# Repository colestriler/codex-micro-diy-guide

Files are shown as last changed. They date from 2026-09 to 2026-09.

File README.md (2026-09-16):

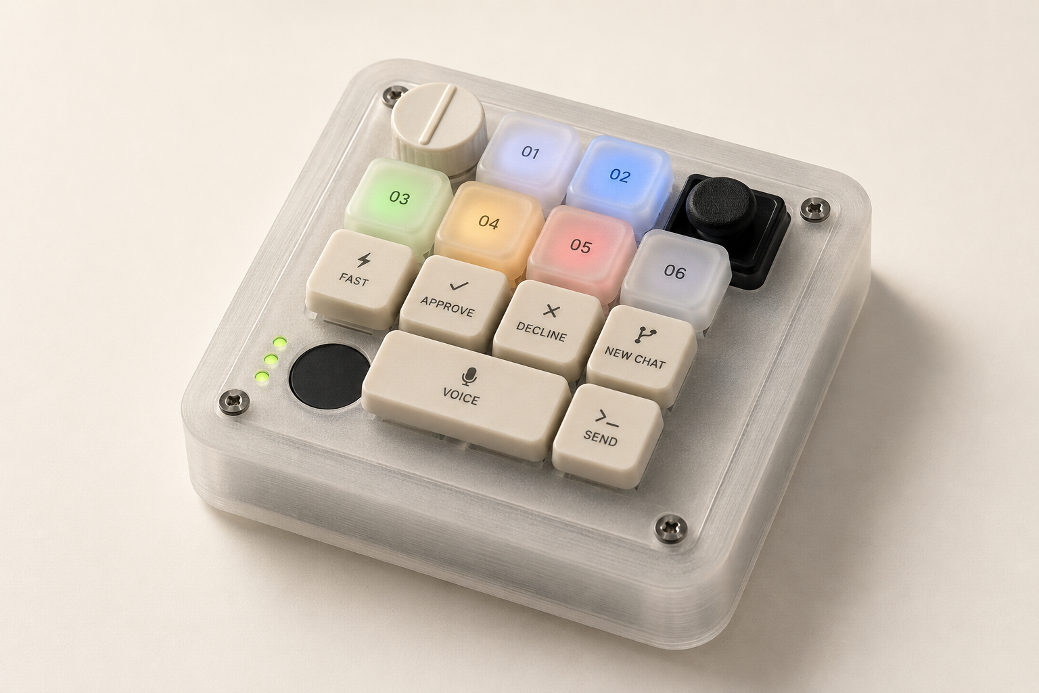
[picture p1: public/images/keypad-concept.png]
Concept render of the DIY Codex Micro keypad with numbered agent keys and labeled controls (https://codexmicro.diy)


*AI-generated concept render of the DIY prototype, with functional key labels.*

# I wanted the OpenAI keyboard, but it was sold out.

So I decided to build one. 

I wanted to buy the [OpenAI × Work Louder Codex Micro](https://openai.com/supply/co-lab/work-louder/). Small keyboard, little dial, glowing keys. Very much my kind of thing.

I have a 3D printer. So I decided to put together a guide to making my own version—and share the files for anyone who wants to do the same.

This is that guide: a way to explore the parts, watch how they fit together, download the CAD, and work through the build. Credit for the original device goes to OpenAI and Work Louder. This project is a tutorial for a DIY recreation of their Codex Micro.

**[Open the interactive build guide →](https://codexmicro.diy)**

## What's here

- An interactive 3D model. Click a part for its print files or a purchase link for bought components.
- An eleven-stage assembly animation, including the bits hidden inside the case.
- Ten clickable assembly lessons with focused CAD views, before/after and replay controls, wiring diagrams, and explanations of how and why each step works.
- Printable STL files, editable STEP files, and parametric CAD source.
- A compact parts checklist that saves your selections in your browser, plus filament choices, wiring, assembly instructions, and starter firmware.
- One continuous page with a table of contents in build order.

## Where the build stands

The CAD is a dimensioned prototype reconstructed from the reference layout and standard parts. It is not the manufacturer's CAD. Earlier enclosure revisions have been printed, and the knob button and rotation have been bench-tested. The latest joystick/tray fits, LED illumination and complete keyboard still need physical confirmation.

The custom KB2040 firmware provides generic USB inputs and manual LED control. **It does not yet reproduce the full native Codex integration.** OpenAI documents native support for the genuine Codex Micro and Creator Micro 2. Retaining genuine electronics is the documented route to those features; adapting the printed case to a donor board still requires measurements and a mechanical revision.

The guide explains both routes so you can decide what to build before buying a pile of parts.

The printable keycaps were updated on September 13, 2026 with flat tops, rounded corners and a 0.5 mm beveled rim for easier printing and labeling. This applies to the shared white/clear single cap and the wide white cap. Start with a stem-fit coupon and one cap before printing the set. The main assembly viewer includes the flat keycaps but retains the older mount and individual baffles. Use the current revision guides for the latest joystick and tray; the hero remains a concept illustration.

## Current CAD downloads

Download the [current STEP set](https://codexmicro.diy/downloads/current-cad/Codex-Micro-current-STEP.zip): 14 current parts and fit samples, plus a partial mounting reference assembly. **Mounting v5** puts the tray screws underneath and the heat-set inserts in bosses under the upper plate. The joystick sits on a separate adapter with locating pegs and raised tab supports. The 10 × 4 mm LED openings and flat keycaps are retained.

Start with the four small prints: upper/lower tray-joint samples, joystick corner and adapter. Reuse the tested adapter in the finished keyboard. Both full plates are new matched v5 parts and remain **WAIT** until both fit tests pass. Reuse M3 × 8 tray screws and M3 × 4 inserts; the joystick needs two longer **M1.6 × 10 mm screws** with the existing nuts. [Interactive CAD and print guide](https://codexmicro.diy/downloads/mounting-v5/guide.html).

Retired mounts, shims and individual baffles are excluded from the current STEP set; historical kits remain in the complete archive.

Run `python3 scripts/package-current-cad.py` after updating a revision kit to synchronize the current exports, refresh the STEP bundle and rebuild the complete archive. The manifest records the source and hash of every included STEP file.

## Run the site

Requires Node.js 22 or newer.

```sh
npm ci
npm run viewer
npm run dev
```

Open `http://localhost:3007`.

```sh
npm run build
npm start
```

`npm run build` regenerates the viewer and checks the catalog, model mappings, geometry buffers, and download links before building Next.js.

The live site is hosted on Vercel. Pushing to `main` automatically builds and deploys the site.

## Project map

- `app/` and `components/`: the single-page Next.js app.
- `data/parts.json`: part descriptions, quantities, specifications, purchase links, and print files.
- `data/instructions.json`: the checked-in assembly, printing, compatibility, and software instructions.
- `data/assembly-lessons.json`: the ten lessons, their part lists and resources, and which CAD components each focused view shows.
- `viewer-src/`: the Three.js assembly player, actual CAD meshes, and model-to-catalog mappings.
- `public/downloads/`: the complete CAD, wiring, firmware, original offline guide, and build package.

To update the model, edit `viewer-src/assembly.js` or its source geometry, then run `npm run viewer`. Every selectable model component maps to a catalog entry in `viewer-src/part-map.json`; subcomponents such as LED boards and copper foil have their own part identifiers.

The CAD source and its Python dependencies live in `public/downloads/cad/` and `public/downloads/requirements.txt`. Keep Python virtual environments outside `public/`. The original CAD and firmware rebuild instructions are included in the downloadable guide.

After editing the CAD, use that Python environment to run `public/downloads/cad/build.py`, `public/downloads/tools/verify.py`, `public/downloads/tools/render.py`, and `public/downloads/tools/make_animation.py`. Then run `scripts/sync-cad.py` to regenerate the viewer geometry, download catalog, offline guide and verified ZIP, followed by `npm run build`.

## Credits

- Original device: [OpenAI × Work Louder](https://openai.com/supply/co-lab/work-louder/).
- Native setup and behavior: [OpenAI's Codex Micro guide](https://learn.chatgpt.com/docs/features/codex-micro).
- 3D rendering: Three.js, with its MIT license included in `viewer-src/THREE-LICENSE.txt`.
- Hero image: generated from the project's CAD using the built-in image-generation tool. [Image prompt](docs/hero-image-prompt.md).
- GitHub icon: [Primer Octicons](https://github.com/primer/octicons), with its MIT license in `public/licenses/octicons.txt`.

An independent DIY tutorial, not an official OpenAI or Work Louder product. Seller links are ordinary product and catalog links; availability can change.

## Learn the wiring one circuit at a time

Start with the [knob and perfboard walkthrough](https://codexmicro.diy/#wiring). Each step includes the action, why it matters, a checkpoint, and saved browser progress. Download the [six-page wiring PDF](https://codexmicro.diy/downloads/wiring-guide/Codex-Micro-LED-Wiring-Guide.pdf) or the [staged tests and libraries](https://codexmicro.diy/downloads/wiring-guide/wiring-starter.zip).

The stages test the knob button, knob rotation and one RGBW LED separately. Install only the selected test as `code.py`; keep your rotation direction setting when changing stages. The optional reasoning-shortcut example requires an app or OS binding. These tests do not provide native Codex integration. Remaining full-keyboard circuits are documented separately in the guide.

The perfboard map describes the connections from our bench walkthrough, including the shared-ground reroute. Software checks validate the intended nets; they do not verify physical solder joints or that the LED lights.

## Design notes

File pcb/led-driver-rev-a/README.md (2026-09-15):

# Codex Micro LED Driver — Rev A prototype

This 36 × 30 mm board replaces the hand-built perfboard section only. JLCPCB
can assemble the level shifter, 330 Ω resistor, 100 nF bypass capacitor,
100 µF bulk capacitor, and two right-angle JST XH connectors.

The connections are deliberately identical at both ends:

| Pin | KB2040 connector J1 | LED connector J2 |
| --- | --- | --- |
| 1 | `+5V` from `RAW` | `+5V` |
| 2 | data from `MO` / `MOSI` | `DIN` through the buffer and 330 Ω resistor |
| 3 | `GND` | `GND` |

The board does not contain the KB2040, key switches, diodes, encoder,
joystick, touch circuit, or RGBW LED boards. Matching three-wire JST XH cable
assemblies are still required. One cable's free end connects to KB2040
`RAW`, `MO`, and `GND`; the other connects to the first LED's `5V`, `DIN`,
and `GND` pads.

## Before ordering

This is an unbuilt first revision. Confirm that the existing single-LED
perfboard circuit lights successfully, then compare JLCPCB's component preview
against `board-top.png`: U1 pin 1 and C2 positive must match the board markers.
Order the smallest prototype quantity first. Inspect the board and test it with
one dim LED before connecting the complete chain.

The 100 µF capacitor matches the current prototype BOM. The finished 14-pixel
chain still needs a measured current and USB-power check. Firmware should keep
brightness limited during initial tests.

## Manufacturing files

- `Codex-Micro-LED-Driver-Rev-A-JLCPCB.zip`: Gerbers, BOM and CPL.
- `manufacturing/gerbers-jlcpcb.zip`: bare-board fabrication archive.
- `bom-jlcpcb.csv`: exact LCSC choices, including SMT/THT classification.
- `cpl-jlcpcb.csv`: placement coordinates in millimetres.
- `codex-micro-led-driver.kicad_pcb`: editable KiCad source.
- `drc-report.txt`: KiCad design-rule results.
- `design-summary.json`: scope and remaining physical checks.

The assembly BOM includes two through-hole JST XH connectors, so choose mixed
SMT + THT assembly if JLCPCB recognizes those parts. Do not silently omit J1 or
J2 if the assembly quote cannot place them.

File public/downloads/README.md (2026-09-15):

# Latest: heat-set baffle tray v3

Uses your existing M3 x 8 screws and Adafruit M3 x 4 inserts. Only lower tray geometry changes from v2; the upper plate and sample can be reused. Print the small lower sample first. See `baffle-tray-v3/guide.html`. Historical notes and files below are superseded.

# Latest: two-layer baffle tray v2

Print only the two samples in `baffle-tray-v2/files/PRINT_FIRST*` first. See `baffle-tray-v2/guide.html`. Full top plate and tray are marked WAIT. This replaces the clip proposal; old files below are retained as history. Four additional M3 × 20 screws and M3 nuts are required for the full build.

# Clip-on baffle update — print two small test pieces first

Open `baffle-snap-v1/guide.html`. The new cup needs matching underside plate clips. Its candidate full plate also includes the flat joystick v3 mount. Physical fit/release and fatigue remain unverified; wait for both fit tests before printing the full plate. The full plate requires supports in its supplied orientation. Old source/assembly geometry below is archived and still shows adhesive cups.

# Current joystick design: flat v3

Open `joystick-flat-v3/guide.html`. Print only the small v3 corner first, flat side down, raised supports up, supports OFF. It uses exposed M1.6 nuts with the same M1.6 × 8 mm screws. The full plate remains a candidate pending fit testing. Older kits below are archived.

# Integrated joystick v2 — print the corner first

Open `joystick-integrated-v2/guide.html`. The full top plate is a candidate pending the corner fit test. Two M1.6 × 8 mm screws and M1.6 nuts, same as v1; no loose shims. Original assembly STEP and original generator still show the old mount. The versioned v2 kit contains the new parametric source and reference assembly.

# Joystick fit-kit update

Joystick update: use the new screw-retained bench fit kit first. The original cradle and full keyboard animation are legacy geometry; the final top-plate attachment is not yet designed or physically verified. Keep your existing top plate until the sample fits.

Use `joystick-fit-v1/guide.html` and `joystick-fit-v1/joystick-fit-sample-v1.zip` in the downloads root. The original cad/build.py still generates the superseded cradle. New source: joystick-fit-v1/build.py. New screws: 2 × M1.6 × 8 mm DIN 912; nuts: 2 × M1.6 DIN 934; tool: 1.5 mm hex key.

# DIY Micro — Rev A

Open `build-guide.html` for the complete specification, bill of materials, links, assembly and firmware instructions.

This is an independent, dimensioned reconstruction of the OpenAI × Work Louder Codex Micro visual layout. It is not the manufacturer's CAD and has not been physically printed or electrically tested.

## Full native functionality

OpenAI documents support for the Codex Micro and Creator Micro 2. Keep the genuine electronics and firmware for the documented integration. The supplied CAD is for the custom hand-wired prototype; it is NOT verified to accept an OEM donor PCB. A donor enclosure requires the measurements in `docs/oem-measurements.csv` and a mechanical revision before printing.

The custom KB2040 firmware supports input scanning, generic USB macros, dial scrolling, joystick arrows, touch-selected banks, and manual RGBW commands. It does NOT implement native Codex task association, live status synchronization, push-to-talk integration, or native device detection. Do not buy custom electronics expecting automatic feature parity.

## Assembly animation

Open `assembly-animation.html` for the offline interactive 3D player, also embedded in the guide. It uses the nine assembled printed-part STEP geometries, plus simplified electronics and fasteners. Play eleven stages, scrub the timeline, rotate/zoom, inspect the underside, or make the case transparent. Cable paths illustrate service slack rather than electrical connections.

Rebuild the animation after exporting updated STEP files with `.venv/bin/python tools/make_animation.py`, then rebuild the guide with `.venv/bin/python tools/make_guide.py`. The Three.js 0.160.1 dependency is vendored with its MIT license.

## CAD

- `stl/` — print-oriented meshes (11 unique parts, some printed multiple times)
- `step/assembly.step` — assembled CAD; REF components are simplified purchased-part envelopes, not printable
- `step/` — individual editable STEP solids
- `cad/build.py` and `cad/parameters.json` — editable parametric source
- `cad/preview.glb` — 3D preview
- `docs/validation.json` — actual checks and limitations

Units: millimetres. Overall prototype case: 110 × 110 × 25 mm, before controls and 5 mm foot. It is deliberately deeper than a custom-PCB design. Standard MX switch centers: 19.05 mm.

Keycap update, 13 September 2026: both cap files now have flat finger surfaces, rounded corners and a 0.5 mm beveled rim. File 08 is shared by the five white command caps and six clear agent caps; file 09 is the white wide cap with two MX sockets 19.05 mm apart. Print top up at 100% scale, with underside supports as needed and sockets kept clear. For a 0.4 mm nozzle, start with 0.10–0.12 mm layers. Print the stem-fit coupon and one cap before the full set; physical fit and finish remain untested.

Rebuild:

```sh
uv venv --python 3.12 .venv
uv pip install --python .venv/bin/python -r requirements.txt
.venv/bin/python cad/build.py
.venv/bin/python tools/verify.py
.venv/bin/python tools/render.py
```

Source research checked 2026-09-06. All electronics and CAD dimensions need a physical fit test before final assembly.

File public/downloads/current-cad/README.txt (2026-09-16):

CODEX MICRO — CURRENT STEP FILES

Current candidate: MOUNTING V5. Physical fit testing pending.
Hidden upward M3 tray screws and separate pegged joystick adapter.
Both upper and lower plates must be the new matching v5 pair.
Keep the existing case, electronics and M3 hardware.

PRINT FIRST — FOUR SMALL PIECES
07_upper_joint_sample_v5: insert bosses belong to the UPPER sample.
07_lower_joint_sample_v5: M3 x 8 screw heads underneath this lower sample.
04_joystick_corner_v5: flat plate corner, locating/screw holes and wire slot.
04_joystick_adapter_v5: separate base, two pegs and raised ear supports.
The adapter can be reused in the final keyboard. Test inserts stay in sample.

AFTER BOTH FIT TESTS PASS
02_top_plate_v5_WAIT: new full upper plate, visible face down for printing.
07_light_tray_v5_WAIT: matching full lower tray, cups up.
Four M3 x 8 screws + four Adafruit M3 x 4 inserts (4.2 mm OD), reused types.
Joystick now needs TWO M1.6 x 10 screws; existing M1.6 nuts are reused.
Prior 8 mm joystick screws are too short for full nut engagement in v5.

The other current parts remain: case, foot, touch cap, knob, flat 1u and
wide 2u caps, switch-fit and stem-fit coupons. No new KB2040 holder added.

REFERENCE ONLY
reference/mounting_v5_assembly_NOT_PRINTABLE.step: upper, lower, adapter,
reference joystick and hardware. Not a complete keyboard or printable part.

UNITS / PRINTING
Millimeters. STEP preserves assembly coordinates; use matching bed-oriented
STLs and the guide's support notes. Adapter prints pegs down with support
under the base. No print-fit, structural or physical assembly claim is made.

https://codexmicro.diy/downloads/mounting-v5/guide.html
manifest.json records source files, quantities, print notes and SHA-256.

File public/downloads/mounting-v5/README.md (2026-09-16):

# Codex Micro mounting v5 — fit-test release

Hidden upward tray fasteners and a separate keyed joystick adapter. Replaces
baffle-tray-v4 + joystick-flat-v3 as the current candidate. Both full plates
change; the old upper/lower pair must not be mixed with these parts.

Start with `guide.html`. `print-first-STLs.zip` contains exactly four small
prints: upper joint sample, lower joint sample, joystick corner and adapter.
Use `WAIT_` full-size files only after both tests pass. The tested adapter can
be reused. STEP files retain assembly coordinates; STLs are bed-oriented.

## Fasteners

- 4 M3 x 8 socket cap screws enter from under the lower tray.
- 4 Adafruit 4255 M3 x 4 inserts (4.2 mm OD) go in the UPPER plate bosses.
- Joint: 3 mm lower grip + 4 mm engagement + 1 mm thread past insert;
  blind tip well leaves 1 mm tip clearance. Insert interference is intentional.
- Joystick uses two M1.6 x 10 DIN912 screws with existing standard M1.6 nuts.
  The prior 8 mm screws are too short for full nut engagement with this adapter.
  Nuts are exposed below the upper plate. No captive nut boxes.
- Existing four corner case fasteners remain. The two joystick tab screws are
  still visible at the joystick; no tray screws appear on the front.

## Design

Upper bosses: 8 mm diameter, 9 mm tall, 3.9 x 4.3 mm starting insert pilots.
Lower tray: original v4 cups and 10 x 4 mm rounded LED openings preserved;
old tall posts shortened to mounting shelves. The upper boss enters a cutout
with 0.2 mm nominal radial clearance.

Adapter: 1.6 mm base; 0.5 / 1.0 mm ear seats; two 3.6 mm pegs, 2 mm long,
in 4 mm plate holes; 2.4 mm joystick clearance holes; 9 x 4 mm wire slot.
Joysticks vary: confirm both ears are supported without bending and the actual
thumb control has full travel. Do not tighten screws to compensate for a gap.

## Reproduce

Python environment with `requirements.txt`: run `python build.py`, then
`python render.py`. Models in references are the immutable input geometry.
Validation is written only after checks pass. `scene.js` and `preview.png`
are generated from the actual CAD geometry.

The community joystick reference is attributed under `reference-model-LICENSE.txt`.
The vendor product is SparkFun COM-09426 / PSP1000:
https://www.sparkfun.com/thumb-slide-joystick.html
M1.6 x 10 screw dimensions:
https://www.accu.co.uk/metric-cap-head-screws/3785-SSCF-M1-6-10-A2
M3 x 8 screw: https://www.mcmaster.com/91290A113/
M3 insert: https://www.adafruit.com/product/4255

## Limits

Nominal CAD collision checks and watertight meshes are not physical validation.
No structural load, fatigue, insert pullout or completed-keyboard tests have
been performed. Real wires, solder, thumb cap travel and driver access require
checking on the samples. Do not claim this is a verified production fit.

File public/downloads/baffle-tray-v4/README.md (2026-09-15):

# Two-layer baffle tray v4 — 10 × 4 mm LED openings

Each compartment now has a **10 × 4 mm bottom opening**, enlarged from v3's 6 × 2.2 mm slot to match the original individual baffle opening size. The opening is centered 5 mm toward the wire side of the LED seat, matching the original offset and leaving a 1.15 mm strip before the inner wall. Corners retain a 0.4 mm radius.

The upper plate, screw posts, heat-set inserts and 9.7 × 9.7 mm LED recesses are unchanged. Reprint only the lower sample or lower tray that you need. Use the same M3 × 8 mm screws and Adafruit M3 × 4 mm inserts. Physical fit remains unverified.

## Feeding a light through

Unplug USB and remove the upper plate so the compartment is open. Turn the LED **edge-first** through the 10 × 4 mm opening, then move it toward the center and turn it flat into its shallow seat. Do this before closing the upper plate over the LEDs. Test your already-soldered light on the small sample before installing inserts; remove the light before heating any insert. During the LED fit check, feed the wires gently and stop if a solder joint catches. Do not pull on the wires to force the LED through.

The CAD checks a nominal 9.1 × 9.1 × 3.1 mm LED body along an edge-first insertion, inward movement, rotation and seating path. Its edge-on envelope has 0.9 mm total clearance in both slot dimensions (0.45 mm per side when centered). Solder, insulation, wire bends and printer tolerances use that clearance and are not modeled. The opening is not large enough to drop this LED through flat. A physical fit check is still required.

## What to print

One `PRINT_FIRST_two_key_baffle_sample.stl`, black PETG. Reuse the v2 upper sample if already printed; otherwise print one `PRINT_FIRST_two_key_top_sample.stl` in white or clear PETG. Both included STL orientations use supports off. 100% scale, 0.4 mm nozzle, 0.15 mm layers, four walls, 100% infill.

After the sample and joystick tests pass: one `WAIT_six_light_baffle_tray.stl` from this v4 kit. The full `WAIT_full_top_plate.stl` is geometrically unchanged from baffle-tray-v2; do not reprint it if you have the two-layer v2 or v3 upper plate. Older snap/adhesive plates are different. Lower tray bottom down, cups up. Full upper plate underside down, joystick seats up; review local support for underside switch recesses (different orientation from the small upper sample).

## Existing hardware

- Full tray: four spare M3 × 8 mm socket cap screws, McMaster 91290A113: https://www.mcmaster.com/91290A113/
- Four M3 × 4 mm heat-set inserts, 4.2 mm OD, Adafruit 4255: https://www.adafruit.com/product/4255
- Sample: two screws and two inserts. Screws can be reused; embedded sample inserts stay there.
- Keyboard total: ten inserts installed (four case, two foot, four tray), plus two for this sample. Existing 50-pack covers these quantities if sufficient spares remain. Original case and foot screws are still required.
- No M3 × 20 screws or loose tray nuts required. Screw heads remain above the upper plate.

The insert dimensions are verified on Adafruit's product page. The existing BOM identifies the screws as M3 × 8; the McMaster part number is also identified as M3 × 8 in the PUNYO project BOM: https://punyo.tech/downloads/Bubble_Gripper_BOM_v2.0.pdf . McMaster's product page could not be retrieved by the research tool. Confirm your packet label and measure under-head length before assembly.

## Insert installation

Unplug USB, remove all electronics, and place the lower tray flat with cups up. Slowly press each heated insert vertically into its top-facing pilot using a suitable insertion tip. Follow the filament/tool heat-setting guidance; no single temperature is prescribed here. Seat flush with the post top. Do not force cold brass into plastic, screw into hot brass, or use the screw as an insertion press. Allow complete cooling before assembly. Stop if plastic distorts or the insert tilts/spins.

Adafruit recommends a heat-set installation tip for alignment: https://www.adafruit.com/product/4255 . The 3.9 mm pilot is a starting fit, not a validated hole for every printer/PETG combination. Trial on the small sample. Do not change the scale of the complete part to alter one hole.

Join the empty layers with the M3 × 8 screws from above, threading them gently into the cooled inserts. Snug only until seated; no loose nuts. Check for rocking, insert rotation, cracks, and screw binding. Then dry-fit real switches, caps, insulated LEDs and leads. Support the tray as you undo its screws. For service, lift the top/tray assembly clear of the case before separating if wiring access requires it.

## Geometry / verification

The upper plate is z22–25; posts meet its underside at z22. Inserts sit flush at z22 and extend to z18 (4 mm length). An 8 mm screw through the 3 mm plate reaches z17: full nominal 4 mm insert engagement plus 1 mm into the relief well. The well floor is z16, leaving 1 mm nominal tip clearance. Screw tips stay entirely inside the posts, 7 mm above the tray bottom.

Each post is 8 mm OD. Nominal radial plastic outside the 4.2 mm insert is 1.9 mm. Printed pilot: 3.9 mm diameter × 4.3 mm depth; 3.4 mm screw-tip relief below, ending at z16. Heat-setting intentionally displaces the pilot wall. CAD collision tests use the installed/melted insert envelope instead of treating that interference as a fault. Heat creep, knurl grip and pullout strength require a physical test.

Mount centers (-16,41.5), (16,41.5), (-41.5,9.525), (41.5,9.525) mm are unchanged. Tray floor z10, LED pockets z10.8. A 0.2 mm insulating adhesive layer plus a 3.1 mm LED yields top z14.1, nominally 0.8 mm below the switch pin envelope. Controller top reference z8.9 gives 1.1 mm tray clearance. Actual wires/solder/component heights still need checking.

LED pockets locate but do not clamp boards. Retain them with one layer of 3M 9474LE polyester-backed mounting tape (0.17 mm excluding liners), within the 0.2 mm adhesive allowance. Cut small pieces; keep LED faces and wire openings clear. Dry-fit and test first: this is strong permanent adhesive. Product: https://www.amazon.com/dp/B0CLJ3RK2B LED leads use floor slots; matrix leads use wall notches. Leave about 20 mm lowering travel in the wires and keep all metal pads isolated. No hot-swap or electrical disconnect is added.

`build.py` checks the nominal LED insertion path and verifies that changes from v3 are confined to the opening regions, with zero upper-plate geometry change. It exports four single-solid watertight printable meshes, checks screw/insert fit, nominal engagement, tip clearance, insertion-tip access, case and electronics envelopes, and tray removal past switches. It does not validate real soldering or physical strength. STEP uses assembled coordinates; STL is print-oriented. Reference assembly is not printable. Viewer and preview use the same CAD.

Run `python build.py` with Python 3.12 and `requirements.txt`. Test both the baffle sample and joystick sample before the full plate. The older main keyboard animation remains a legacy illustration. See this folder's interactive guide for v4.

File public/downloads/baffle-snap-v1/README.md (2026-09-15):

# Snap-on light baffle — first fit test

Print **two small pieces, one of each**:

1. `files/PRINT_ONE_test_plate_with_clips.stl`
2. `files/PRINT_ONE_snap_baffle.stl`

The plate sample includes both flexible clips; there are no separate clips to print. No glue, screws, nuts or new electronics are required for this test. The old glue-mounted cup and old top plate do not have these matching features.

## Why the clips are on the plate

The existing cups are 18.7 mm across on 19.05 mm key centers: only 0.35 mm separates neighboring cups. Side release tabs would be difficult to reach. This design puts two flexible arms on the underside of the plate. They pass through windows in the cup floor, and their hooked ends are accessible underneath. Pinch the two ends toward one another and lower the cup. The clips are integral to the plate, so a broken clip would require a plate repair/reprint; test them on this inexpensive coupon first.

The baffle rim still meets the underside of the plate. Two 0.8 mm thick beams extend down beside the switch and LED; their hooks latch under the cup floor. Nominal retaining overlap is 0.35 mm, axial clearance is 0.1 mm, and the target release movement is about 0.5 mm per tip. Do not treat those as measured print tolerances. Keep the two clip channels clear of solder, diode leads and wires.

## Printing the two small samples

- Use PETG for the plate/clip sample. White matches the full plate; clear is also suitable for the mechanical test. Use black PETG for the cup so it blocks light. These are not TPU designs; PLA is not the recommended clip-test material.
- Print at 100% scale in millimeters, with a 0.4 mm nozzle, 0.10 mm layers, four walls and 100% infill for the small samples. Use your printer's existing PETG temperature/cooling profile.
- Keep the supplied STL orientations: plate's visible face on the bed, clips standing upward; cup flat bottom on the bed, cavity upward.
- Start with supports OFF for these two small samples. The plate's MX clip lands bridge/cantilever only a short distance; the hook has a short ramp and a 0.35 mm retaining ledge. Inspect the sliced preview: each 0.8 mm beam must have continuous extrusion paths and each hook must exist. If your slicer omits a beam or a hook prints poorly, stop and report it instead of forcing the joint.
- Leave the parts to cool before removing them from the bed. Clean strings from the floor windows; do not sand away the retaining lips or bend the long clips sideways while cleaning.

## Test empty first

1. Keep USB disconnected. Do not install or solder the switch or LED yet.
2. Hold the plate sample with its two clips pointing down. Orient the cup open side up. The two narrow floor windows line up with the clips; the larger wire notches are on the other pair of walls.
3. Slide the cup upward gently so the clips enter those windows. You can gently pinch the tips as they emerge below the cup to help them through. Stop if the arms buckle, a hook catches sideways or the cup needs force.
4. Release both clips. Their hooks should catch the underside of the floor when the cup rim reaches the plate. Check that both hooks have emerged and the cup stays attached under its own weight.
5. Pinch both exposed ends toward the center and lower the cup. Press the plastic tips, not the wires or switch. The cup should release without prying its rim away from the plate.
6. Repeat about ten gentle attach/release cycles. Stop for whitening, cracking, permanent bending, excessive looseness or difficult access. This is a fit and usability test, not a validated fatigue rating. Send photos if either clip fails to engage or release.

## Then dry-fit the real components

After the empty mechanism works, clip one real switch into the sample from above. Its own retention tabs must latch normally without touching the added clips. Confirm full key travel. Try the removable cup again.

Place one **unpowered** Adafruit 4776 board in the shallow LED pocket, LED facing the switch, with an insulating layer beneath its pads. The 0.6 mm deep pocket leaves a 0.6 mm floor. With a modeled 0.2 mm insulation layer, the LED clears the conservative pin keepout by 0.5 mm; actual solder and tape thickness still need checking. Check for clearance from the switch's plastic pegs, metal pins and future solder joints. The CAD uses simplified keepout envelopes, not an exact Gateron switch model; your dry fit is required.

The cup is mechanically removable, but a wired LED remains connected. Leave a service loop long enough to lower the cup clear of the switch (start by checking a 20 mm drop on the bench), route wires through the open notches, and keep them away from both latch channels. Never pull on solder joints. Full electrical disconnection would need a connector and is not included in this revision.

Do not wire all six cups until the print fit, switch fit and one powered LED light-leak test have passed. Some leakage through the service openings is possible and needs a real LED test.

## Full plate: wait

`files/WAIT_full_plate_flat_joystick_and_baffle_clips.stl` combines the latest flat joystick mount v3 with twelve clips for the six agent-key cups. It preserves the other original switch holes and case attachment geometry. It is provided for CAD review and later printing only.

**Printing the full plate differs from printing the small coupon.** The supplied full-plate STL is face down with clips pointing up. The joystick's raised supports project on the bed side, so support is needed beneath the raised-off-bed plate face as well as any unsupported local features. Do not reuse the v3 corner's supports-OFF instruction for this full plate. Review the entire layer preview and support interface before printing; this orientation/support strategy is not physically validated. Both joystick and baffle samples must pass first.

The site's original full-keyboard animation still shows the earlier adhesive cups. Use this kit's preview and `reference_fit_assembly_NOT_PRINTABLE.step` for the new clip mechanism. The STEP assembly includes simplified reference blocks that are not printable parts.

## Validation and source

The three print meshes are watertight and single connected solids. The seated cup has no nominal overlap with the plate/clips. A downward pull without releasing the clips produces positive latch interference. All six cups and the candidate plate clear the original case geometry and one another. Simplified lower-switch, pin and LED envelopes clear the cup and clips.

A cantilever calculation estimates approximately 0.36% surface strain at the modeled release movement. It does not account for FDM layer adhesion, local stress concentration, material creep, actual print dimensions or repeated cycles. It is not FEA or a strength guarantee. Release travel is checked geometrically against conservative keepouts; insertion/release motion has not been experimentally measured. See `validation.json` for limits.

Rebuild with Python 3.12: install `requirements.txt` in a virtual environment, then run `python build.py`. Inputs under `references/` are existing project STEP files, not extra prints.

Design references:
- [Formlabs snap-fit design guide](https://formlabs.com/blog/designing-3d-printed-snap-fit-enclosures/) — cantilever and strain principles; not PETG FDM fit validation.
- [Gateron North Pole Yellow 2.0 specification](https://gateron.com/u_file/2311/22/file/GATERONNewNorthPole20yellow-KS-7Y10B050NW-Y39.pdf) — exact switch identification; actual retention tabs and pins still require a trial fit.
- [Adafruit 4776](https://www.adafruit.com/product/4776) — LED board used by this project.

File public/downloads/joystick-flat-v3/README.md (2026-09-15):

# Flat joystick mount — v3

Print **only `files/PRINT_FIRST_flat_joystick_corner_v3.stl`** first. It is one piece with a flat 3 mm base and two raised mounting-tab seats. There are no nut boxes, underside bosses, deep recesses or separate shims.

The 28.7 × 28.7 mm test corner is cropped from the same solid as the candidate full top plate. The full plate is 94 × 94 mm with a 3 mm main thickness. The two local seats rise 0.5 mm (A) and 1.0 mm (B) above the top face. Their heights reproduce the v1 starting shims, not new measurements of your joystick.

## Print this corner

- One STL at 100% scale, units millimeters.
- Keep the supplied orientation: **flat underside on the bed, raised supports facing UP**.
- Existing PETG, any color. 0.4 mm nozzle, 0.10 mm layers, four walls, 100% infill for this small test.
- **Supports OFF for the test corner.** It has a flat underside and straight through-holes. A brim is optional if you need help with bed adhesion.
- Clean strings from the holes without changing the support heights. No support material should need removing from a body recess or nut tunnel because neither exists in v3.

## Attachment

Screw head → joystick mounting tab → raised support → plate → exposed nut underneath.

The stationary body rests directly on the flat top. The screws hold the two supported ears down. Each nut bears against the flat underside. Hold the nut with small pliers while turning the screw from above. Keep the pliers on the metal nut, not the joystick or its wiring. Use gentle tightening; don't bend a tab or crush the plastic.

The joystick ears face the outer edge of the plate. The four solder pads face the neighboring key row and sit over the rectangular wire opening. Seat B is the one nearest the larger case-screw hole. Do not use v1/v2 orientation or wiring photos to infer pad order: verify the actual component labels and supplier orientation before soldering.

## Hardware — same sizes

- Two M1.6 × 8 mm DIN 912 socket-head screws, 0.35 mm pitch, 3 mm head diameter, 1.6 mm head height: [supplier specifications](https://www.accu.co.uk/metric-cap-head-screws/3784-SSCF-M1-6-8-A2).
- Two M1.6 DIN 934 nuts, 3.2 mm across flats, 1.3 mm thick: [supplier specifications](https://www.accu.co.uk/hexagon-nuts/7882-HPN-M1-6-A2).
- 1.5 mm hex key and small pliers to hold the exposed nuts.

Your existing 8 mm screws fit the modeled stack and fully engage the nuts. Their ends extend approximately 1.2 mm (A) and 1.7 mm (B) past the nuts. CAD checks show clearance from the original case; keep the exposed tips clear of real wires. No new screw size, washers or electronics are specified. Supplier stock is not verified.

## Fit check

1. Unplug the KB2040. Dry-fit the joystick on the loose test corner before using screws. The body should sit flat and both ears should touch their raised seats. No loose shims. If there is rocking or a gap, stop and report it instead of using screw force to close it.
2. Insert the two screws through the joystick ears and supports. Start each nut by hand underneath. Hold the nut with pliers and gently tighten from above. Check that both nuts sit flat and the fixed joystick housing does not shift, lift or rock.
3. Move the thumb cap fully in every direction and diagonally. Check clearance from the screw heads, supports and plate. The CAD joystick reference does not reproduce the exact textured thumb cap, so this real movement check is required.
4. Remove the old full top plate and rest the test corner on the bare case ledge, aligned with the rounded outer corner and larger M3 case hole. It replaces that area of the plate; it is not an insert for the old recess. Check that both nuts and screw tips clear the case post and wiring. Fit the nuts while the plate is off the case, where they are accessible.
5. Share a top and side photo and report any gap, wobble, binding or case interference before printing the full plate.

## Candidate full plate

`WAIT_flat_top_plate_v3.stl` is included for inspection and later printing. Wait until the corner passes. The joystick area uses the same flat design. Other switch, encoder, touch, indicator and M3 case-hole geometry is preserved from the original plate.

The full STL is also face UP. Unlike the small corner, the full plate includes the original underside MX clip reliefs: inspect those small overhangs in the slicer and add localized support if required. Support-free guidance above applies specifically to the test corner. After printing the full plate, dry-fit the actual neighboring switches and caps and check their full travel before assembly.

The full-keyboard animation and original `downloads/step/assembly.step` remain legacy geometry. Use this kit's preview and `reference-assembly_NOT_FOR_PRINTING.step` for the v3 mount. Reference STEP files and the assembly are not additional prints.

## CAD verification and source

Both exported print meshes are watertight, single connected volumes, placed on Z=0. Automated CAD checks cover reference-joystick interference, original-case interference, screw shaft clearance at both documented hole layouts, hardware clearance, nominal adjacent keycaps and flat nut-bearing surfaces. The mount adds no plastic below the original plate underside. `validation.json` records these checks and the limits. These are geometry checks, not physical fit, stiffness, durability or printer validation.

Install `requirements.txt` in a Python 3.12 virtual environment, then run `python build.py`. `parameters.json` exposes the joystick center, support heights and 2.4 mm screw-clearance holes. The holes accommodate the small discrepancy between the two source mounting layouts; printed fit still needs checking.

Exact-SKU footprint: [SparkFun-Switches.lbr](https://github.com/sparkfun/SparkFun-Eagle-Libraries/blob/main/SparkFun-Switches.lbr), JOYSTICK-PSP1000, COM-09426. Community reference: [marbastlib PNT_psp1000](https://github.com/ebastler/marbastlib/blob/6b0a9a73f579e377816d60b58eac2b3252de7868/3dmodels/PNT_psp1000.step), credited to Hendrik Roth, rotated and translated in the assembly. Its CERN-OHL-P-2.0 license is included. Neither source is a measurement of your exact part.

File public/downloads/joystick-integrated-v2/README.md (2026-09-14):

# Integrated joystick mount — v2 fit test

Print **only `files/PRINT_FIRST_joystick_corner_v2.stl`** for now. The holder and both tab supports are part of this one print. No loose shims.

This is a 30.5 × 30.5 mm corner cut directly from the redesigned full top plate. It retains the actual rounded case corner, M3 mounting hole and nearby switch-opening edges. The rest of the plate is unchanged outside the joystick area. The candidate full plate is included as `WAIT_full_top_plate_v2`; do not print it until the corner passes the fit checks.

## How it mounts

The stationary joystick body sits in a shallow 1 mm recess. Its two ears sit on built-in supports at 0.5 mm and 1.0 mm above the body seat, reproducing the starting v1 shims. Two screws clamp those ears to metal nuts in pockets under the plate. The main plate is still 3 mm thick; only the nut bosses project 4.8 mm below it. Nothing is stacked on top as a separate stand.

The joystick is rotated 180 degrees relative to the v1 bench holder. The mounting ears face the outside/right edge of the keyboard; the four solder pads face the neighboring key row. A 9 × 4 mm opening beneath the pads routes the wires down into the case. Do not reuse the old center hole or infer pad order from the old orientation.

Its center is now (29, 30.5) mm in the original plate coordinates. A relief around the existing case screw pillar provides clearance. CAD checks found no interference with the original case or nominal neighboring 18 mm keycaps. The real textured thumb cap's shape and travel are not accurately represented by the community reference: physical movement must be checked.

## Print settings — support needed for the shallow recess

- One corner STL, 100% scale, millimeters. Do not mirror or scale to fit.
- Use existing PETG. Any color works for this test; white matches the final plate.
- 0.4 mm nozzle, 0.10 mm layers, four walls, 100% infill for the small test.
- Leave the STL in its supplied orientation: visible face down, the two nut bosses pointing up. The final full plate uses the same orientation.
- Enable build-plate supports beneath the shallow joystick recess and the lower mounting-ear seat. Inspect your slicer's layer preview: those recessed surfaces begin above the bed and must not print into air. Keep the wire opening clear and use support blockers for the narrow nut tunnels and screw slots; the 3.5 mm nut-tunnel roofs are short bridges.
- Remove supports carefully from the body seat and ear seat, and clean strings from the wire opening and nut slots. A leftover support layer can lift the joystick and create a false gap. Do not sand the support heights down to force a fit.

## Hardware

Same as v1: **two M1.6 × 8 mm DIN 912 screws**, **two M1.6 DIN 934 nuts**, and a **1.5 mm hex key**. No additional electronics or new fastener size.

- [Screws](https://www.accu.co.uk/metric-cap-head-screws/3784-SSCF-M1-6-8-A2): 0.35 mm pitch, 3 mm head diameter, 1.6 mm head height.
- [Nuts](https://www.accu.co.uk/hexagon-nuts/7882-HPN-M1-6-A2): 3.2 mm across flats, 1.3 mm thick.

Check stock and pack sizes with the seller. The screws are not the M3 screws used to attach the top plate to the case.

## Fit checks — do these before the full plate

1. Unplug the KB2040. Remove print supports, then try the joystick in the loose corner with no screws or nuts. Do not put any of the old loose shims in this mount.
2. Identify the rounded outer corner and its larger M3 case hole. The joystick ears go on that outer side. The ear near the case hole uses support B; the other uses support A. The four underside solder pads go over the rectangular through-opening toward the key row. Keep its original metal cage and mounting ears intact.
3. Confirm the body sits flat without rocking and both tabs touch their seats. If a tab has a gap or a support lifts the body, stop and report it. Do not tighten screws to close a gap.
4. If the dry fit passes, turn the sample over and slide an M1.6 nut into each side pocket. Insert the M1.6 screws through the joystick ears from above and tighten gently. Hold a nut with tweezers if needed; do not force it into an undersized pocket. Check that the screws engage the nuts without bottoming out.
5. Move the thumb cap all the way in each direction and diagonally. The stationary housing should not lift, twist or rock, and the cap must not catch the plate, screw heads or edges. This physical check is required because the reference model does not reproduce the real cap's motion.
6. Remove the original full top plate and gently place this corner on the bare case ledge, aligning its rounded corner and original M3 case hole. It is a replacement test section, not an insert that goes into or on top of the old plate. The nut bosses and screw tips must clear the case post and internal wiring. Do not force it down or pull it down with the case screw.
7. Share a top and side photo, and whether there is any rocking, gap, binding or case interference. Only after these pass should the full plate be printed. The full plate will need an additional real neighboring-switch/keycap travel check during dry assembly.

## CAD and limitations

Both exported print meshes are watertight, single connected solids, at Z=0. The corner is cropped from the same CAD solid as the full plate. The generator checks reference joystick, case, hardware and static neighboring keycap clearances. This is geometric validation, not physical strength testing, slicer validation or confirmation of the actual thumb cap's movement. `validation.json` records the limits.

The original full-keyboard animation and `downloads/step/assembly.step` are still legacy geometry. Use this kit's preview and `reference-assembly_NOT_FOR_PRINTING.step` to inspect the new mount. Files under `references/` are generator inputs, not additional prints.

Install `requirements.txt` in a Python 3.12 virtual environment and run `python build.py` to regenerate. Support offsets are in `parameters.json`; their current values reproduce the v1 starting shims rather than claiming new measured dimensions.

Reference: SparkFun COM-09426 footprint in [SparkFun-Switches.lbr](https://github.com/sparkfun/SparkFun-Eagle-Libraries/blob/main/SparkFun-Switches.lbr), package JOYSTICK-PSP1000. Community model: [marbastlib PNT_psp1000](https://github.com/ebastler/marbastlib/blob/6b0a9a73f579e377816d60b58eac2b3252de7868/3dmodels/PNT_psp1000.step), credited to Hendrik Roth. The community geometry is rotated and translated in the reference assembly; its CERN-OHL-P-2.0 license is included. Its hole centers differ slightly from the SparkFun footprint; clearance slots accommodate both. Neither is a measurement of your exact joystick.

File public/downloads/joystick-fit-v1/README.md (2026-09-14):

# Joystick fit holder — v1

A 26.5 × 26.5 mm bench sample for SparkFun COM-09426. It supports the stationary housing, locates it with low stops, provides adjustable screw slots and leaves an open passage beneath the solder pads. The removable spacers support the mounting ears without pulling them down when screws tighten.

Open `guide.html` for pictures, print-file links and hardware links.

## Print first

- `files/holder.stl`: one, flat bottom down, 0.2 mm layers, 4 walls, 100% infill.
- `files/shim_A_0.5mm.stl`: one, flat down, 0.1 mm layers, 100% infill.
- `files/shim_B_1.0mm.stl`: one, flat down, 0.1 mm layers, 100% infill.
- The other two shim files are optional thickness alternatives; keep each A/B shim at its own mounting position. All STLs are already centered and placed on Z=0 for printing. Units are millimeters; use 100% scale.
- Use your existing PETG, including clear PETG. PLA is also suitable for this bench sample. Transparency is not required. A 0.4 mm nozzle is suitable. Supports off; the small nut tunnels require bridging. Clean strings from slots. Do not force nuts into an undersized printed tunnel.

## Hardware for the retention test

- Two M1.6 × 8 mm, 0.35 mm pitch, DIN 912 socket-head screws; head diameter 3 mm, head height 1.6 mm.
- Two M1.6 DIN 934 hex nuts, 3.2 mm across flats, 1.3 mm thick.
- 1.5 mm hex key for the specified screws; tweezers help position the nuts.

Screw specifications/product: https://www.accu.co.uk/metric-cap-head-screws/3784-SSCF-M1-6-8-A2

Nut specifications/product: https://www.accu.co.uk/hexagon-nuts/7882-HPN-M1-6-A2

Equivalent fasteners with those dimensions can be sourced elsewhere. Live availability and delivery are not verified. The previously discussed M2 screws are superseded for this sample: their 3.8 mm heads slightly intersect one corner of the community reference model. M1.6 leaves clearance in the nominal 2 mm joystick holes. Do not substitute the keyboard's M3 case screws.

## Fit check — before soldering or tightening

1. Unplug the KB2040. Work with the joystick loose on the bench. Keep its mounting ears and metal retention cage intact.
2. Face the holder's open U-shaped end away from you; the two screw platforms are on your left. A is the far-left platform near the open end; B is the near-left platform near the closed end.
3. Put the 0.5 mm A shim on A and the 1 mm B shim on B. Their cut-away inner corners face the main joystick body. They sit on the two screw platforms, with slots aligned. You can rotate each loose shim in the slicer preview to compare its shape with the assembly STEP; do not flip its A/B designation.
4. Lower the joystick onto the four small inner support blocks. Its four underside solder pads face the open end. The two ears should align with the two platforms. The pads remain accessible over the open passage; later the insulated wires can turn down toward the existing top-plate opening.
5. Check that the stationary body rests flat, both ears are supported, and the thumb control moves freely. If a spacer makes the body rock, stop and try the thinner spacer for that position. If there is still a gap or it will not seat, send top and side photos before tightening. Do not use screws to pull a bent or unsupported ear into place.
6. Once the dry fit works, slide one nut into each side tunnel. Put the screws down through the joystick ears and shim slots, then turn them gently into the nuts. The slots allow slight adjustment; hold a nut with tweezers if it turns. The two nuts must be engaged. Tighten only enough to stop movement; tiny plastic ears need very little force.
7. Move the thumb control fully in all directions, then gently check for lift or rocking of the fixed housing. The screw tips should stay inside the holder. If a screw bottoms out, an ear bends, or movement binds, stop. Do not add more torque.

You can perform steps 1–5 without the new screws. The next useful feedback is one top photo and one side photo with the joystick resting in the sample.

## What this sample establishes

It tests housing clearance, mounting alignment, spacer height, fastener access, and room for wires. Attachment of this holder to the keyboard top plate, surrounding keycap clearance, and the full thumb-cap motion envelope still need checking. Keep your current top plate; do not drill, glue or reprint it for this test. The holder's full base sits above a plate; it does not press into the old 22 mm recess.

The sample raises the joystick body bottom 7 mm above its underside. This height provides accessible nut tunnels and screw-tip clearance for the bench test; the final integrated mounting height may change after fit feedback.

## CAD validation and provenance

`build.py` creates the holder, four shim choices, and a STEP reference assembly. `validation.json` records the checks: one valid solid per printable part; no solid overlap with the community joystick; shafts fit at both SparkFun and marbastlib hole layouts; selected screw heads and nuts clear the modeled housing and holder. These checks do not establish physical fit, FDM hole accuracy, or motion limits. Threads are simplified in the reference assembly. The original removable thumb cap is not represented accurately by the community model.

The source model hole centers differ from SparkFun's footprint. This sample intentionally accommodates both; it is not called a verified BOM or final production design.

- Exact-SKU footprint: https://github.com/sparkfun/SparkFun-Eagle-Libraries/blob/main/SparkFun-Switches.lbr (`JOYSTICK-PSP1000`, COM-09426).
- Community model: https://github.com/ebastler/marbastlib/blob/6b0a9a73f579e377816d60b58eac2b3252de7868/3dmodels/PNT_psp1000.step
- marbastlib credits Hendrik Roth for the PSP-1000 model. Its CERN-OHL-P-2.0 license is included in `reference-model-LICENSE.txt`. The reference assembly incorporates that model, rotated and translated; the manufactured joystick itself is not a printable part.

Only print files named `holder.stl` and `shim_*.stl`. The STEP assembly includes purchased reference hardware and is for inspection.

## Rebuild the sample

Using Python 3.12, install `requirements.txt` in a virtual environment and run `python build.py`. The community STEP reference is included under `references/`; its license is included in `reference-model-LICENSE.txt`. This source regenerates the five sample prints, reference assembly, preview and validation report. It does not redesign the full keyboard plate.

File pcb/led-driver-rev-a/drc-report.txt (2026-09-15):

** Drc report for codex-micro-led-driver.kicad_pcb **
** Created on 2026-09-15T01:02:50 **
** Report includes: Errors, Warnings, Exclusions **

** Found 0 DRC violations **

** Found 0 unconnected pads **

** Found 0 Footprint errors **

** Ignored checks **
    - Footprint has no courtyard defined
    - Track endpoint not centered on via
    - Tuning profile track geometries
    - Footprint doesn't match symbol's footprint filters
    - Footprint component type doesn't match footprint pads

** End of Report **

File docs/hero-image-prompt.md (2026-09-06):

# Keypad concept render

Generated with the built-in image-generation tool using `public/downloads/docs/cad-preview.png` as the geometry reference. Saved as `public/images/keypad-concept.png` and used in the site overview and GitHub README. This is a concept illustration of the unbuilt DIY prototype.

## Prompt

Use case: product-mockup / sketch-to-render
Asset type: wide website hero and GitHub README image, photorealistic concept render.
Reference image 1 is the CAD geometry of the actual DIY keypad. Preserve the exact physical layout, proportions, twelve keycaps, four corner screws, raised key plate, rotary knob, thumb slide joystick, and touch pad. Turn this CAD visualization into an exceptionally realistic, beautifully lit studio product photograph of the same device.
Scene: the keypad alone on a warm off-white seamless desk/background, soft daylight from upper left, gentle realistic contact shadow, no other props. Three-quarter view from the front, at about 40 degrees above the desk. Landscape 3:2 image, centered keypad occupying about 75% of the frame width, comfortable breathing room, entire device visible, no crop.
Materials: subtly frosted translucent natural PETG case with delicate real 3D-print layer texture; matte ivory command keycaps and dial; softly translucent agent keycaps, black joystick and round touch surface; realistic brushed metal screw heads. Six agent keys illustrate soft white, blue, green, amber, subdued red, and unlit status, with restrained internal light diffusion. Premium but plausible DIY prototype, believable molded/printed surfaces rather than waxy CGI.
Exact key layout viewed facing the front edge:
Back row: rotary dial at far left; agent keys '01', '02'; black thumb slide joystick at far right.
Second row: four agent keys '03', '04', '05', '06'.
Third row: four white keys 'FAST', 'APPROVE', 'DECLINE', 'NEW CHAT'.
Front row: black round touch pad at far left; one wide white key spanning the middle two positions labeled 'VOICE' with a small microphone icon; white key 'SEND' at far right.
Labels: crisp, small dark charcoal key legends printed on the top of each cap, properly aligned with its perspective. Include a small lightning icon on FAST, checkmark on APPROVE, cross on DECLINE, branching arrow on NEW CHAT, and terminal/send icon on SEND, above the readable word. Agent numbers should be clean and restrained.
Constraints: exactly match the reference control layout. No extra keys. Do not include the reference image's title, dimensions, labels outside the keys, annotation text, watermark, surrounding UI, or logos. This should look like a professional macro product photograph; physically credible fine detail and subtle material imperfections.

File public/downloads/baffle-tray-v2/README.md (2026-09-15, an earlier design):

# Codex Micro: two-layer baffle tray v2

Experimental mechanical design. CAD checks pass; physical print fit, assembly access, strength and optical performance are not verified.

## Print these two first

- `files/PRINT_FIRST_two_key_top_sample.stl` — one, white or clear PETG. Visible face DOWN as supplied. 48 × 26.95 × 3 mm.
- `files/PRINT_FIRST_two_key_baffle_sample.stl` — one, black PETG. Flat bottom DOWN, cavities UP. 40 × 26.45 × 12 mm.

100% scale; 0.4 mm nozzle; 0.15 mm layers; four walls; 100% infill; supports OFF for these two samples. Check the sliced holes, floor slots and wall paths. Do not scale to adjust fit.

These are literal crops of the full plate and tray, not a differently dimensioned mock-up. The sample contains two illuminated-key positions and the two rear mounting points. It does not verify the full assembly against your case, encoder, joystick, controller or complete harness.

## What it is

The upper plate holds the switches. A separate lower tray combines the six light cups, LED locating pockets and four 8 mm diameter solid posts. Four metal through-bolts clamp the top plate to the posts; loose exposed nuts bear on the flat underside. No plastic snap arms, glue or captive nut boxes attach the tray.

The lower piece covers just the six illuminated keys, not the whole keyboard. This stepped footprint leaves space for other controls. Existing case geometry is retained. The candidate upper plate is the flat joystick v3 plate with four new holes, without snap-baffle clips. Existing top plates do not have these holes; print the matching candidate after the fit tests rather than improvising a drilling operation.

## Hardware

Full assembly: four M3 × 20 mm fully threaded DIN 912 socket cap screws and four ordinary M3 DIN 934 hex nuts. Test sample: two pairs, reusable in final build. These are additional to the original case and joystick hardware.

- Screw: https://www.vital-parts.co.uk/socket-cap-screws-din-912/13260-hsc912-m3-20-a2
- Nut: https://www.accu.co.uk/hexagon-nuts/7888-HPN-M3-A2

Reference screw head is 5.5 mm diameter × 3 mm high; nut is 5.5 mm across flats × 2.4 mm thick. Use a 2.5 mm hex key plus 5.5 mm wrench/small socket. Stock and shipping not verified. Black equivalents must match these dimensions. Do not substitute the short case screws or M1.6 joystick screws. Longer screws reduce case/wiring clearance.

Heads remain visible above the upper plate. Nuts are exposed underneath. No washers are included in the modeled stack. Tighten only until the parts seat without rocking; PETG can creep or crush under excessive clamp force. Inspect for loosening after use.

## Assembly / learning test

1. USB disconnected. Clear printing burrs and strings. Screws should pass freely through the 3.4 mm holes, not cut threads into them.
2. Put the cup openings toward the underside of the upper sample. Insert screws from above and finger-start the exposed nuts below. Hold each nut with a wrench; gently snug the screw.
3. The cup rims and posts should meet the upper plate with no rocking. Snap in two real switches from above and test the keycaps through full travel.
4. Unscrew the lower sample to expose switch pins for soldering. These screws only release the lighting tray, not the soldered switches from the upper plate.
5. Dry-fit the real 9.1 × 9.1 × 3.1 mm LEDs in the 9.7 mm square pockets. Pockets locate, but do not positively retain, the LEDs. Use thin removable electrically insulating adhesive beneath each board; total allowance is 0.2 mm. Cover rear pads and keep light-emitting faces clear. Thicker foam is not covered by the clearance check.
6. LED wires pass down through the 6 × 2.2 mm floor slots. Switch/diode leads pass through the 6 mm wide top notches on all four sides. Keep metal ends clear and leave about 20 mm of usable lowering travel in the harness. There is no electrical disconnect in this revision.
7. Reassemble without trapping wires. Check actual solder joints and switch pins remain clear of LEDs. Test one correctly wired LED for light leakage before committing to the full lighting chain.

For service in the finished keyboard: unplug USB, undo case screws and lift the upper plate and tray together far enough to access the nuts without stressing the attached controller/wires. Support both pieces. Undo the four tray nuts and lower the tray. Do not attempt to pull it down through the case floor or force it past fixed wires.

## Full files — WAIT for fit tests

- `files/WAIT_full_top_plate.stl`: one upper plate, 94 × 94 × 4 mm overall. Underside down as supplied, joystick seats up. Review shallow MX underside recesses in the slicer; local support may be needed. It deliberately has a different orientation from the small upper coupon.
- `files/WAIT_six_light_baffle_tray.stl`: one black PETG tray, 91 × 45.325 × 12 mm. Flat bottom down; all cups and posts up. Supports off; four walls and 100% infill.

Also pass the separate joystick v3 physical fit test before printing the full upper plate. STEP files use assembled coordinates. STL files are translated to the bed and oriented for printing; do not overlay the STLs to infer assembly alignment. `reference_assembly_NOT_PRINTABLE.step` includes reference electronics envelopes and is for viewing only.

## Dimensions and checks

Coordinates relative to the center of the original upper plate:
- Mounts: (-16, 41.5), (16, 41.5), (-41.5, 9.525), (41.5, 9.525) mm.
- Upper plate: z22–25 mm (joystick seats up to z26).
- Lower tray: z10–22 mm, floor generally 1.8 mm, cup walls 1.2 mm.
- LED pocket floor z10.8 mm (0.8 mm remaining plastic), insulated LED bottom z11 mm, top z14.1 mm.
- Nominal switch pin envelope begins z14.9 mm: 0.8 mm vertical gap.
- Approximate controller top z8.9 mm: tray floor clearance 1.1 mm. Real solder, wiring, mounting tape and component heights must be checked.
- Screws extend from z25 to z5; nuts z7.6–10. Tips protrude 2.6 mm below nuts, remain 2.6 mm above the modeled case floor, and must be kept clear of wires.

`build.py` checks each printable export is a single valid watertight solid; checks tray/plate/case separation, approximate control envelopes, 13 switch/pin envelopes, six LED clearances, screw/nut intersections and nut bearing area; samples the downward tray-removal path after lifting the assembly out of the case. `validation.json` records results and limits. This is not a load simulation or a complete vendor-component assembly.

The old main keyboard animation still shows individual adhesive cups. This folder's guide and CAD are the current two-layer proposal. Archived clip files remain for history and should not be mixed with this design.

## Rebuild

Install `requirements.txt` in a Python 3.12 environment and run `python build.py` from this directory. The bundled STEP references are the project's existing case and flat joystick v3 top plate. `preview.png`, `scene.js` and `scene.json` are generated from the same CadQuery shapes as the print exports. `guide.html` uses local Three.js (license included); it works as a downloaded local page as well as on the website.

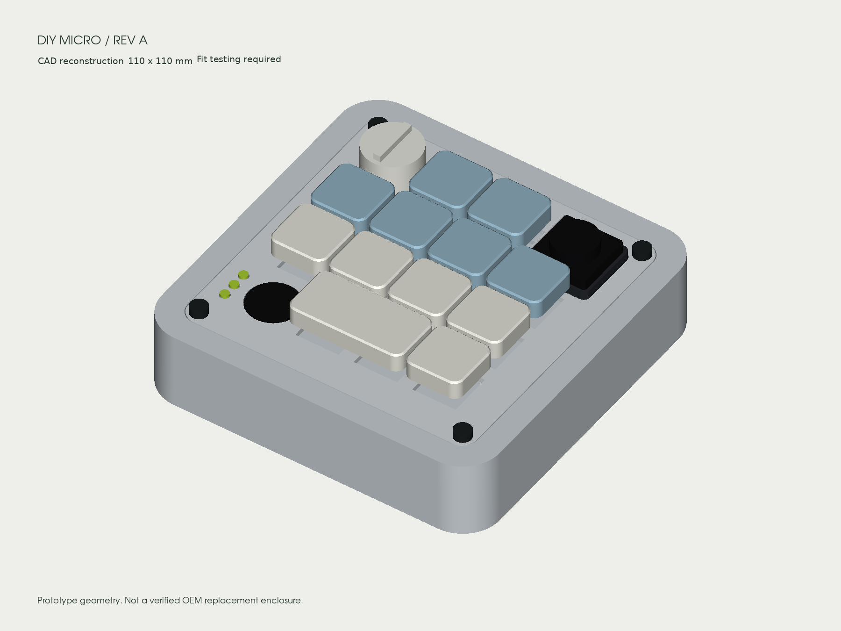
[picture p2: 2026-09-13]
public/downloads/docs/cad-preview.png

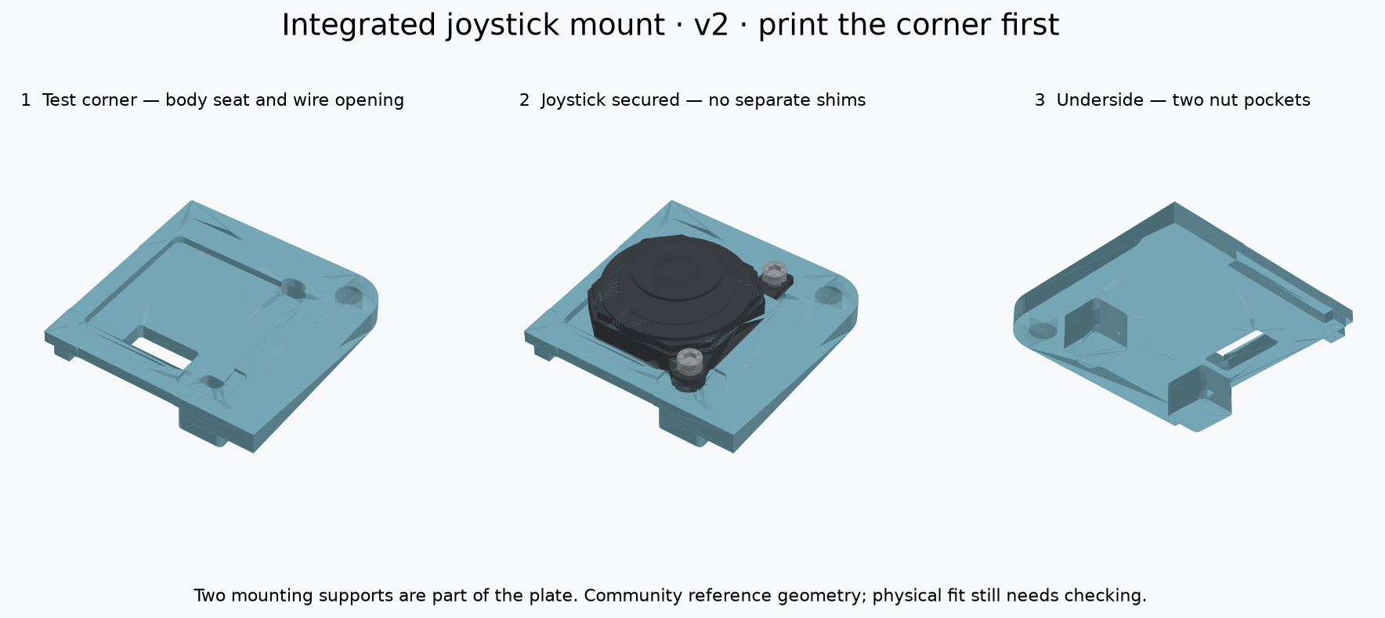
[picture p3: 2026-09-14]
public/downloads/joystick-integrated-v2/preview.png

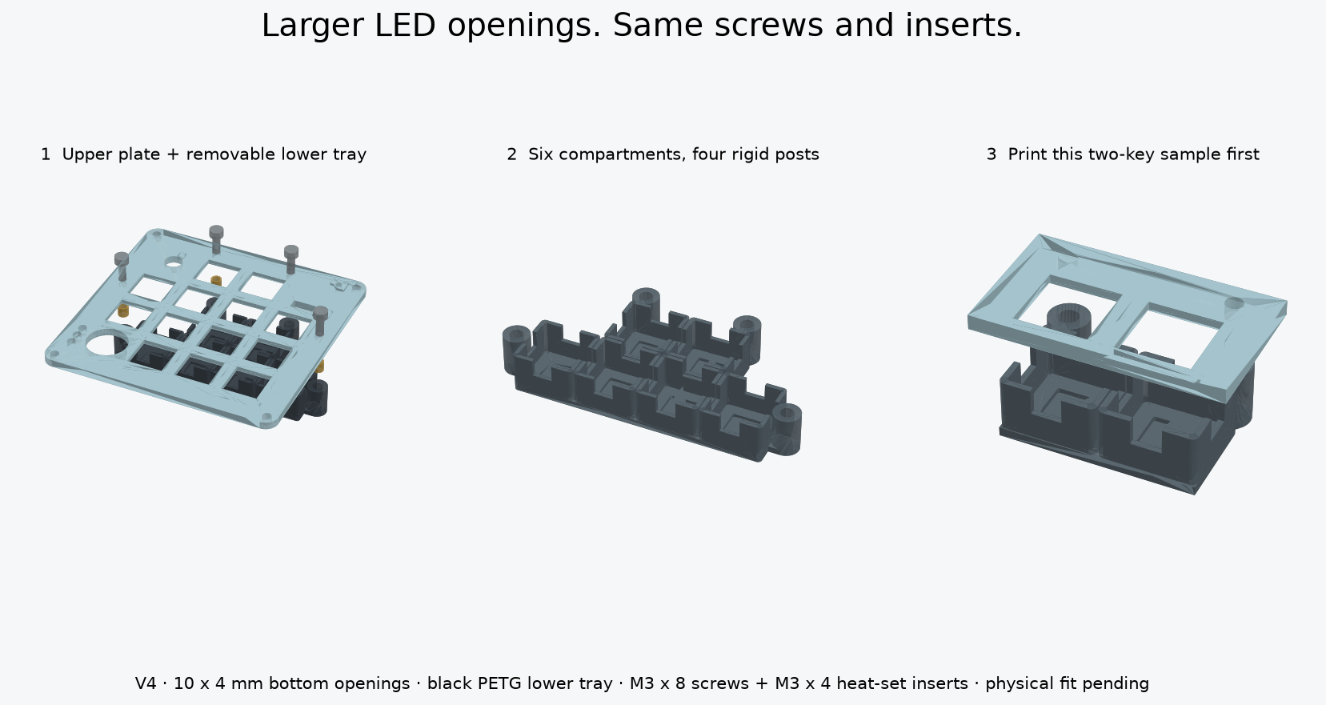
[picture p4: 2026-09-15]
public/downloads/baffle-tray-v4/preview.png

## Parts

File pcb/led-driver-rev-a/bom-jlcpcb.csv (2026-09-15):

Designator | Comment | Footprint | JLCPCB Part # | MPN | Assembly
U1 | SN74AHCT1G125DBVR | SOT-23-5 | C7484 | SN74AHCT1G125DBVR | SMT
R1 | 330R 1% | 0603 | C23138 | 0603WAF3300T5E | SMT
C1 | 100nF 50V X7R | 0603 | C14663 | CC0603KRX7R9BB104 | SMT
C2 | 100uF 16V | SMD,D6.3xL5.4mm | C2887276 | RVT100UF16V67RV0016 | SMT
J1,J2 | JST XH 3-pin right-angle | Through Hole,Right Angle,P=2.5mm | C157928 | S3B-XH-A(LF)(SN) | THT

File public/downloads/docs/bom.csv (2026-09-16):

route | item | quantity_to_buy | quantity_used | estimated_USD | url | notes
native | Creator Micro 2 Pro | 1 | 1 | check seller | https://worklouder.cc/creator-micro-2 | Officially supported; Pro required to also match Bluetooth; availability unconfirmed
native | Codex Micro alternative | 1 | 1 | 230.00 | https://openai.com/supply/co-lab/work-louder/ | Alternative to Creator Micro 2; page was out of stock; do not buy both
native | Frosted MX Pure keycaps | 1 set | 6 1U | check seller | https://worklouder.cc/wrk-mx-pure | For visible agent colors; product page says pre-order
custom | Adafruit KB2040 | 1 | 1 | 8.95 | https://www.adafruit.com/product/5302 | USB-C RP2040 board; no Bluetooth
custom | Gateron New North Pole Yellow 2.0 | 1 pack of 35 | 13 | 19.04 | https://www.gateron.com/products/gateron-new-north-pole-yellow-20-switch-set | Transparent top AND bottom; normal MX type; no Choc or Hall switches
custom | SparkFun COM-09426 thumb slide joystick | 1 | 1 | 5.95 | https://www.sparkfun.com/thumb-slide-joystick.html | PSP1000 style; v5 pegged adapter uses M1.6 x 10 screws and exposed nuts; physical fit test first.
custom | Adafruit rotary encoder 377 | 1 | 1 | 4.50 | https://www.adafruit.com/product/377 | 6 mm D shaft M7 panel bushing; nut and washer; included knob is fallback
custom | Adafruit RGBW mini NeoPixels 4776 | 2 packs of 10 | 14 | 9.90 | https://www.adafruit.com/product/4776 | 6 agent lights plus 8 perimeter; must use GRBW firmware
custom | 74AHCT125 DIP level shifter | 1 | 1 | check seller | https://www.adafruit.com/product/1787 | 5 V supply; translates 3.3 V data to pixels
custom | 1N4148 diodes | 2 packs of 10 | 13 | check seller | https://www.adafruit.com/product/1641 | One per physical switch; band toward matrix row
custom | 28 AWG silicone ribbon | 1 m 10 conductors | as needed | check seller | https://www.adafruit.com/product/3890 | Signals and short LED wiring; use 24-26 AWG for power trunk
custom | Translucent MX caps optional | 1 pack of 10 | 6 | 4.95 | https://www.adafruit.com/product/4956 | Replaces printed translucent 1U caps
custom | White MX caps optional | 1 pack of 10 | 5 | check seller | https://www.adafruit.com/product/4998 | Replaces printed white 1U caps; wide cap still custom
custom | M3 x 4 mm heat-set inserts OD4.2 | 1 pack of 50 | 10 installed + 2 for tray sample | 5.95 | https://www.adafruit.com/product/4255 | Existing pack; four case, two foot, four tray; 2 additional inserts remain in sample. Test 3.9 mm pilot first.
custom | M3 x 8 mm screws | 1 small pack | 6 | estimate 3-6 | https://www.mcmaster.com/products/screws/thread-size~m3/length~8-mm/ | Four top socket caps; two foot low-profile heads max6 mm diameter max1.7 mm high
custom | Passives and prototype board | 1 small assortment | see guide | estimate 8-15 | https://www.adafruit.com/category/34 | 330 ohm x1; 1M ohm x1; 1k ohm x3; 100nF x1; 100uF 10V x1; three 3mm LEDs; perfboard max25x20mm
custom | Copper foil and insulation | 1 small roll each | as needed | estimate 8-12 | https://www.adafruit.com/search?q=copper%20tape | 13mm copper touch disk; polyimide tape; thin foam tape
custom | LED mounting tape - 3M 9474LE | 1 pack of 5 sheets (12 x 9.5 inches) | Small pieces; less than one sheet | 20.88 | https://www.amazon.com/dp/B0CLJ3RK2B | 0.17 mm polyester-backed 300LSE tape excluding liners; one layer within 0.2 mm tray allowance. Strong permanent adhesive; dry-fit first. Price checked 2026-09-15; may change.
custom | USB-C DATA cable | 1 | 1 | estimate 5-10 | https://www.adafruit.com/search?q=USB%20C%20cable | Connector overmold must fit 15x8mm rear tunnel
custom | Rubber foot material and optional weights | 1 strip and 4 washers | as needed | estimate 4-8 | https://www.mcmaster.com/products/rubber/ | Adhesive rubber 1-2mm; optional M8 fender washers OD24 max thickness2mm
materials | Clear or natural PETG 1.75mm | 1 spool | approx150g allowance | estimate 20-30 | https://shop.polymaker.com/products/petg | Choose Clear; case and six agent caps; buy spool not refill if no empty spool
materials | White PETG 1.75mm | 1 spool | approx100g allowance | estimate 20-30 | https://shop.polymaker.com/products/petg | Plate white command caps knob and foot; clear plate optional
materials | Black PETG 1.75mm | 1 small spool | approx50g allowance | estimate 15-25 | https://shop.polymaker.com/products/petg | New lower baffle tray and touch cap; use black PETG for the screwed tray; test sample first.
custom | Clear waterslide decal paper optional | 1 pack of 20 sheets | part of 1 sheet | 15.99 + sealer | https://www.hayespaper.com/products/inkjet-printer-waterslide-decal-paper | Optional printed legends; inkjet version requires inkjet printer and suitable sealer; print shop alternative
custom | Joystick adapter v5 M1.6 × 10 mm DIN 912 screws | 2 | 2 | check seller | https://www.accu.co.uk/metric-cap-head-screws/3785-SSCF-M1-6-10-A2 | New length for v5; previous 8 mm screws too short. Reuse M1.6 nuts; 1.5 mm hex key.
custom | Joystick fit holder M1.6 DIN 934 hex nuts | 2 | 2 | check seller | https://www.accu.co.uk/hexagon-nuts/7882-HPN-M1-6-A2 | Reuse existing nuts; exposed beneath v5 upper plate. 3.2 mm across flats, 1.3 mm thick.
hardware | Tray: reuse McMaster 91290A113 M3 x 8 screws | 4 spare from existing pack | 4 (2 reused from sample) | already specified | https://www.mcmaster.com/91290A113/ | No long bolts or loose tray nuts; requires four spare Adafruit 4255 heat-set inserts.

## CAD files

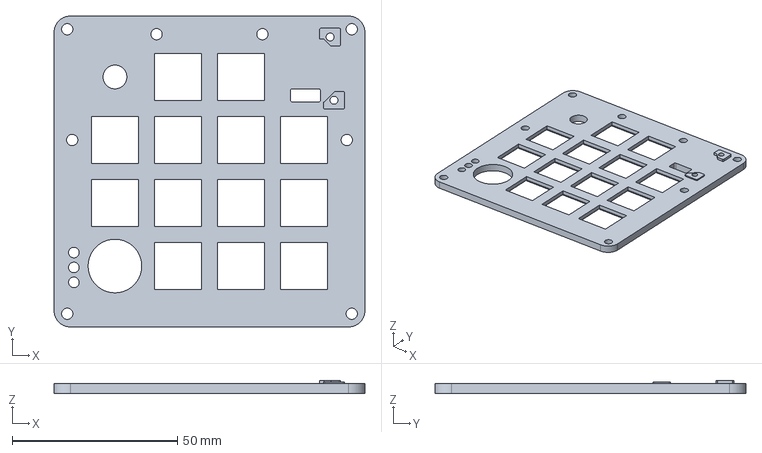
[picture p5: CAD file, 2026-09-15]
public/downloads/baffle-tray-v4/files/WAIT_full_top_plate.step
94.0 x 94.0 x 4.00 mm

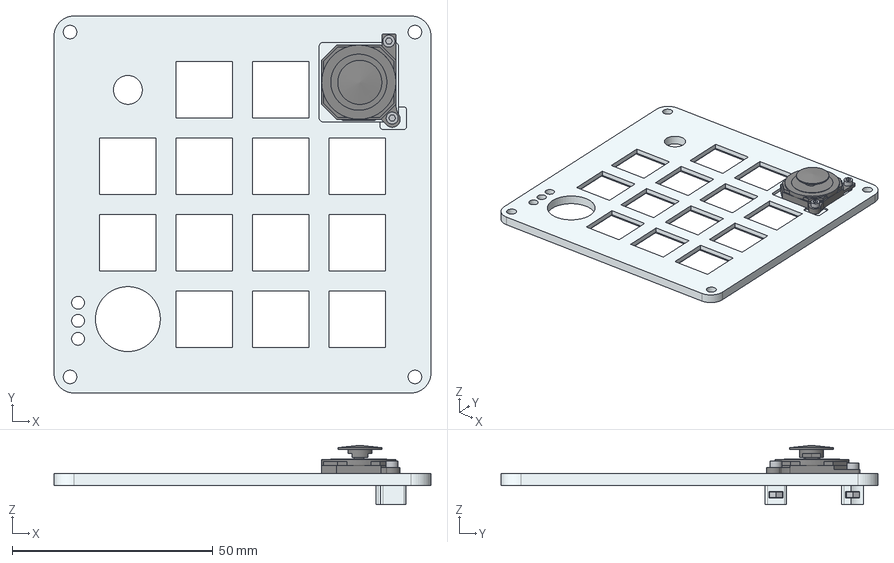
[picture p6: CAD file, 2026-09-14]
public/downloads/joystick-integrated-v2/files/reference-assembly_NOT_FOR_PRINTING.step
94.0 x 94.0 x 14.8 mm
PRINT_full_plate
REFERENCE_joystick_NOT_PRINTABLE
BUY_M1_6x8_A
BUY_M1_6_nut_A
BUY_M1_6x8_B
BUY_M1_6_nut_B

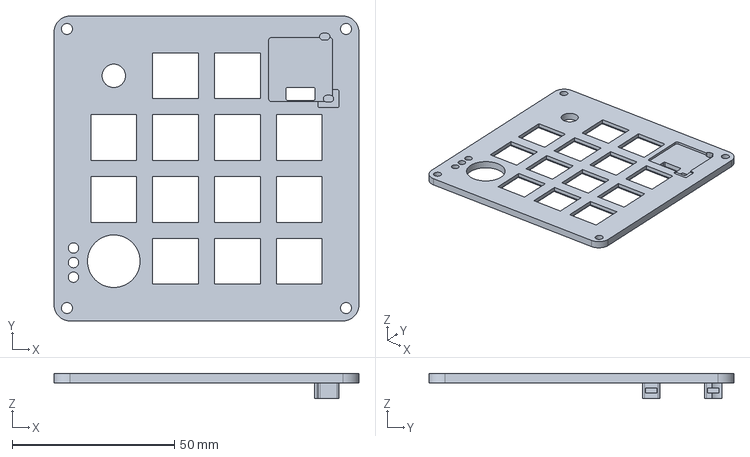
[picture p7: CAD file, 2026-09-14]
public/downloads/joystick-integrated-v2/files/WAIT_full_top_plate_v2.step
94.0 x 94.0 x 7.80 mm

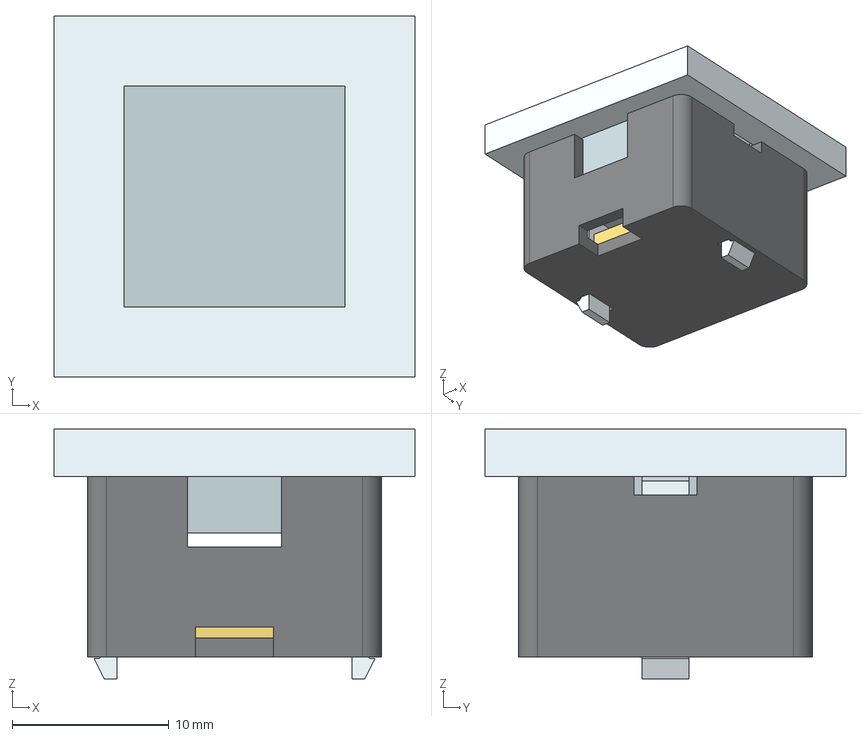
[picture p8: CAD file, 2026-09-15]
public/downloads/baffle-snap-v1/files/reference_fit_assembly_NOT_PRINTABLE.step
23.0 x 23.0 x 15.9 mm
PRINT_test_plate
PRINT_removable_cup
REFERENCE_lower_switch_envelope
REFERENCE_LED_envelope

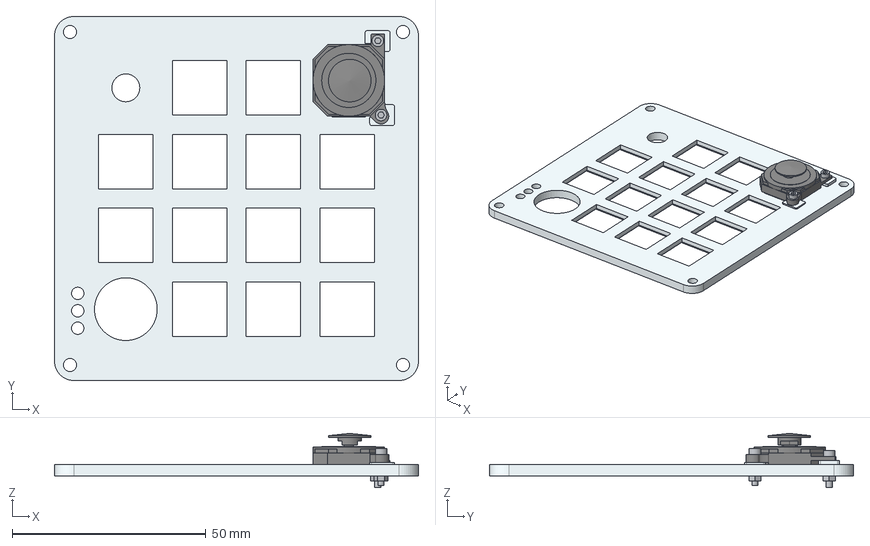
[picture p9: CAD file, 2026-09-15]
public/downloads/joystick-flat-v3/files/reference-assembly_NOT_FOR_PRINTING.step
94.0 x 94.0 x 14.0 mm
PRINT_full_plate
REFERENCE_joystick_NOT_PRINTABLE
BUY_M1_6x8_A
BUY_M1_6_nut_A
BUY_M1_6x8_B
BUY_M1_6_nut_B

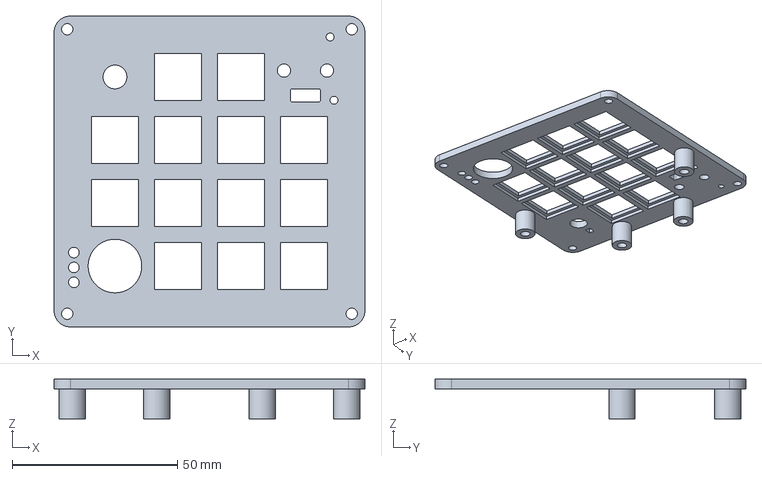
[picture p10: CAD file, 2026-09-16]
public/downloads/mounting-v5/files/WAIT_full_top_plate.step
94.0 x 94.0 x 12.0 mm

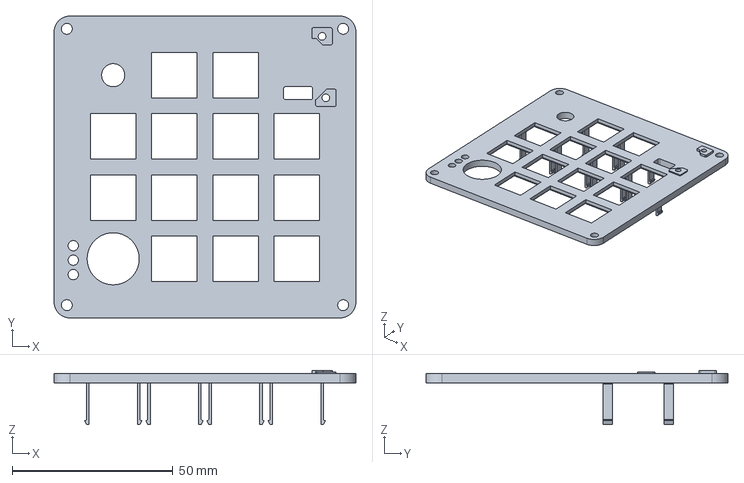
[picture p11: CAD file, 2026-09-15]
public/downloads/baffle-snap-v1/files/WAIT_full_plate_flat_joystick_and_baffle_clips.step
94.0 x 94.0 x 16.9 mm

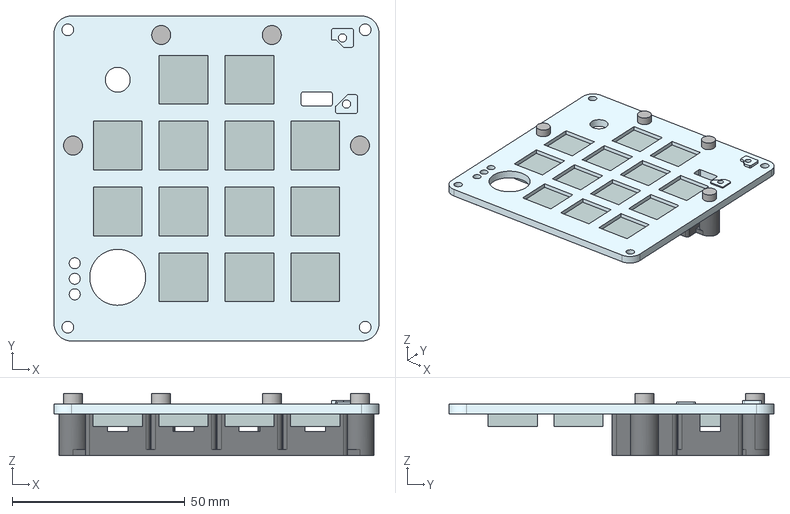
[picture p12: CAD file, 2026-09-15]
public/downloads/baffle-tray-v4/files/reference_assembly_NOT_PRINTABLE.step
94.0 x 94.0 x 18.0 mm
PRINT_upper_plate
PRINT_lower_baffle_tray
REUSE_M3x8_screw_0
REUSE_M3x4_heatset_insert_0
REUSE_M3x8_screw_1
REUSE_M3x4_heatset_insert_1
REUSE_M3x8_screw_2
REUSE_M3x4_heatset_insert_2
REUSE_M3x8_screw_3
REUSE_M3x4_heatset_insert_3
REF_switch_envelope_0
REF_switch_envelope_1
REF_switch_envelope_2
REF_switch_envelope_3
REF_switch_envelope_4
REF_switch_envelope_5
REF_switch_envelope_6
REF_switch_envelope_7
REF_switch_envelope_8
REF_switch_envelope_9
REF_switch_envelope_10
REF_switch_envelope_11
REF_switch_envelope_12
REF_LED_envelope_0
REF_LED_envelope_1
REF_LED_envelope_2
REF_LED_envelope_3
REF_LED_envelope_4
REF_LED_envelope_5

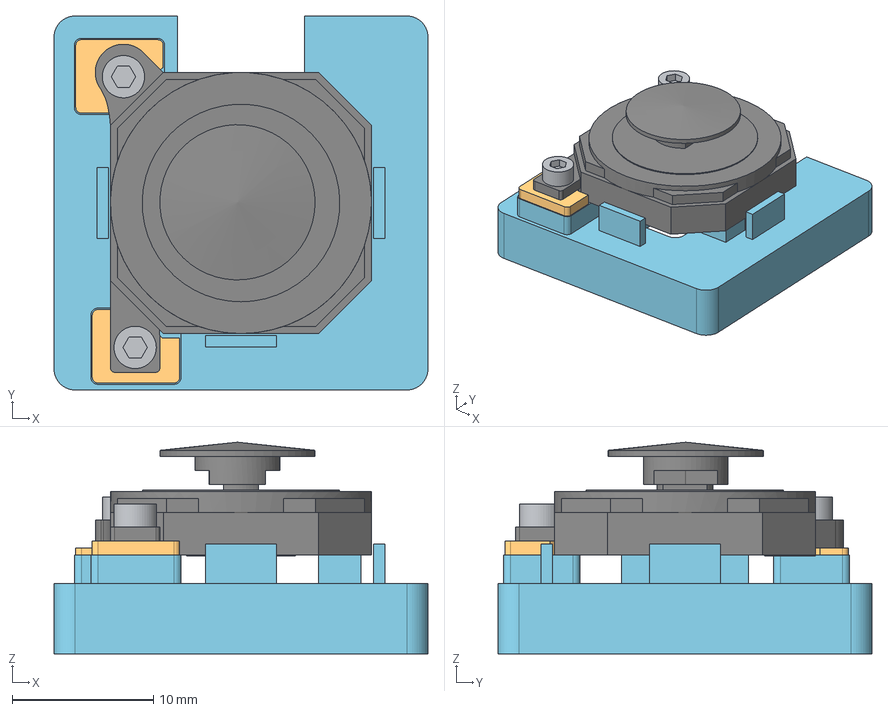
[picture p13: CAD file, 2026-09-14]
public/downloads/joystick-fit-v1/files/reference-assembly.step
26.5 x 26.5 x 15.0 mm
PRINT_holder
REFERENCE_community_joystick_NOT_PRINTABLE
PRINT_shim_A_0.5mm
PRINT_shim_B_1.0mm
BUY_M1_6x8_screw_A
BUY_M1_6_nut_A
BUY_M1_6x8_screw_B
BUY_M1_6_nut_B

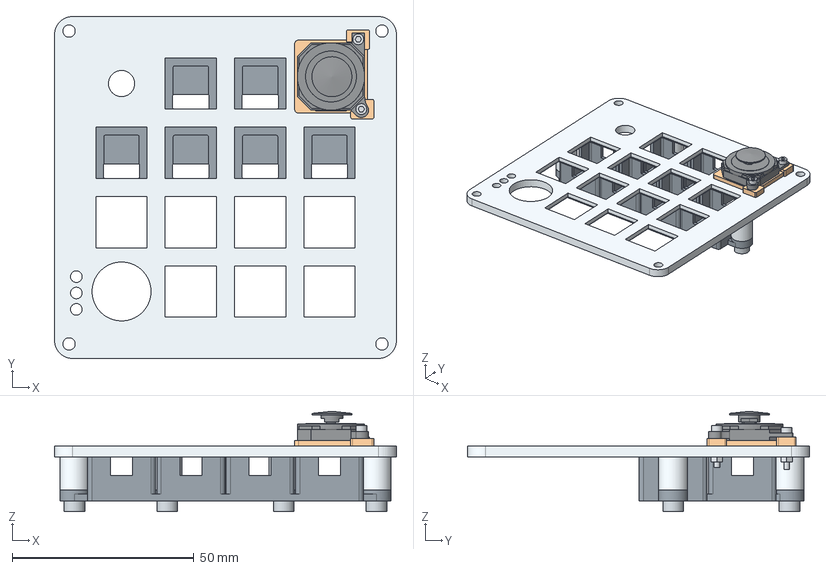
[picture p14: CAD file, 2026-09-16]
public/downloads/mounting-v5/files/reference_assembly_NOT_PRINTABLE.step
94.0 x 94.0 x 27.6 mm
Upper_plate
Lower_light_tray
Removable_joystick_adapter
REFERENCE_joystick
M3x8_upward_screw_1
M3x4_heat_set_insert_1
M3x8_upward_screw_2
M3x4_heat_set_insert_2
M3x8_upward_screw_3
M3x4_heat_set_insert_3
M3x8_upward_screw_4
M3x4_heat_set_insert_4
M1_6x10_joystick_screw_A
M1_6_exposed_nut_A
M1_6x10_joystick_screw_B
M1_6_exposed_nut_B

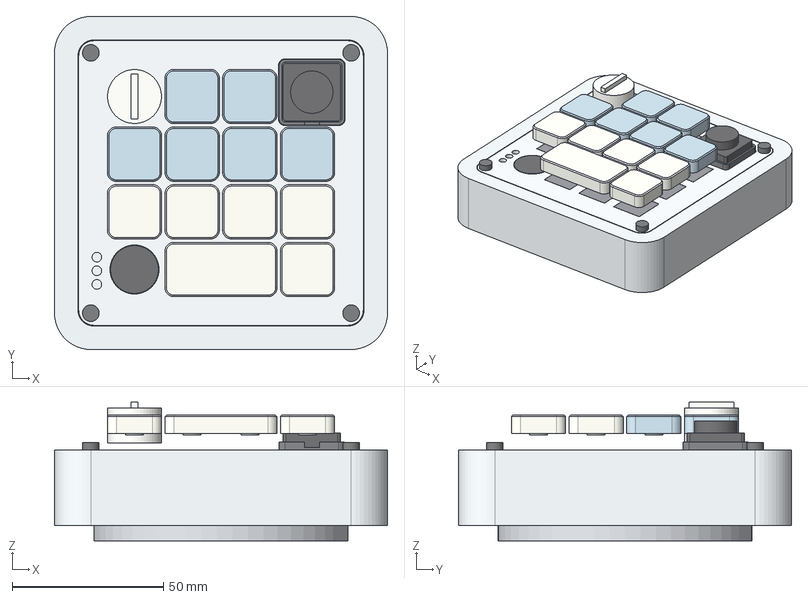
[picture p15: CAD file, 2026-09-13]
public/downloads/step/assembly.step
110.0 x 110.0 x 45.8 mm
case
switch_plate
round_foot
joystick_cradle
touch_cap
encoder_knob
light_baffle_1
REF_RGBW_LED_1
light_baffle_2
REF_RGBW_LED_2
light_baffle_3
REF_RGBW_LED_3
light_baffle_4
REF_RGBW_LED_4
light_baffle_5
REF_RGBW_LED_5
light_baffle_6
REF_RGBW_LED_6
REF_MX_switch_R1C2
keycap_R1C2
REF_MX_switch_R1C3
keycap_R1C3
REF_MX_switch_R2C1
keycap_R2C1
REF_MX_switch_R2C2
keycap_R2C2
REF_MX_switch_R2C3
keycap_R2C3
REF_MX_switch_R2C4
keycap_R2C4
REF_MX_switch_R3C1
keycap_R3C1
REF_MX_switch_R3C2
keycap_R3C2
REF_MX_switch_R3C3
keycap_R3C3
REF_MX_switch_R3C4
keycap_R3C4
REF_MX_switch_R4C2
REF_MX_switch_R4C3
REF_MX_switch_R4C4
keycap_R4C4
wide_keycap
REF_PSP_joystick_envelope
REF_KB2040_envelope
REF_screw_-43.0_-43.0
REF_screw_-43.0_43.0
REF_screw_43.0_-43.0
REF_screw_43.0_43.0

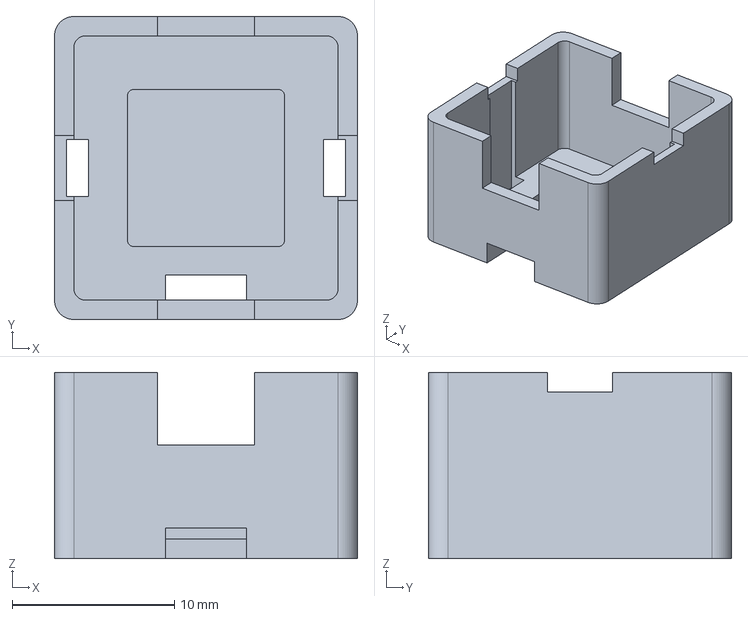
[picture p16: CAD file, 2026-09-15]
public/downloads/baffle-snap-v1/files/PRINT_ONE_snap_baffle.step
18.7 x 18.7 x 11.5 mm

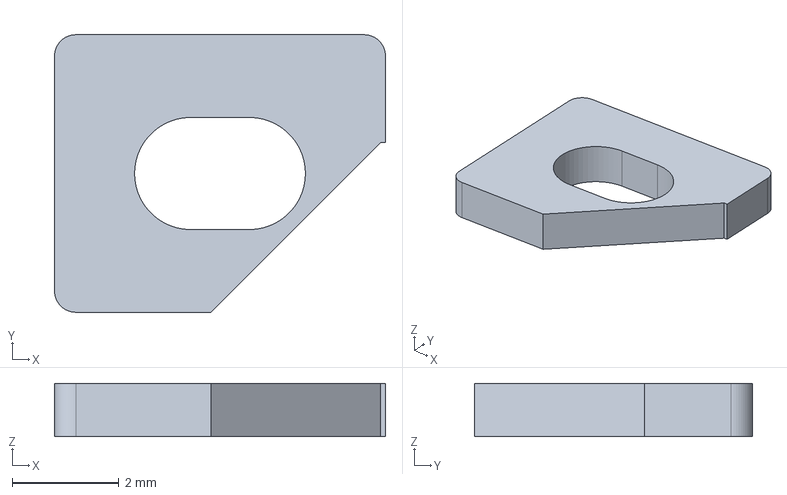
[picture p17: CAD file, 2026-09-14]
public/downloads/joystick-fit-v1/files/shim_A_1.0mm.step
6.20 x 5.20 x 1.00 mm

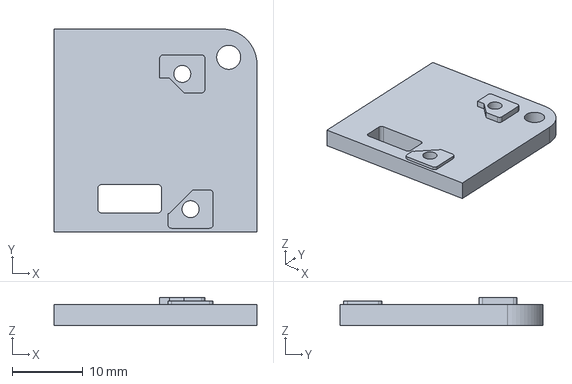
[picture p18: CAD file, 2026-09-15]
public/downloads/joystick-flat-v3/files/PRINT_FIRST_flat_joystick_corner_v3.step
28.7 x 28.7 x 4.00 mm

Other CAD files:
public/downloads/mounting-v5/files/PRINT_FIRST_lower_joint_sample.step
public/downloads/mounting-v5/references/tray-v4.step
public/downloads/stl/07_heatset_six_light_tray_v4_WAIT.stl
public/downloads/baffle-snap-v1/files/PRINT_ONE_snap_baffle.stl
public/downloads/baffle-snap-v1/files/PRINT_ONE_test_plate_with_clips.step
public/downloads/baffle-snap-v1/files/PRINT_ONE_test_plate_with_clips.stl
public/downloads/baffle-snap-v1/files/WAIT_full_plate_flat_joystick_and_baffle_clips.stl
public/downloads/baffle-tray-v2/files/PRINT_FIRST_two_key_baffle_sample.step
public/downloads/baffle-tray-v2/files/PRINT_FIRST_two_key_baffle_sample.stl
public/downloads/baffle-tray-v2/files/PRINT_FIRST_two_key_top_sample.step
public/downloads/baffle-tray-v2/files/WAIT_full_top_plate.step
public/downloads/baffle-tray-v2/files/WAIT_six_light_baffle_tray.step
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

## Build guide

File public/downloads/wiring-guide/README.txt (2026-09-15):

CODEX MICRO - START WITH ONE CIRCUIT AT A TIME

1. Install CircuitPython for Adafruit KB2040. This guide targets CircuitPython 10.x.
2. Copy the contents of lib into CIRCUITPY/lib. These are Python-source libraries.
3. Back up the code.py already on your board to your computer.
4. Choose ONE file from firmware, copy it to CIRCUITPY and name it code.py.

button-test.py: button on A2/G types a. No rotation wires needed yet.
knob-test.py: TX/RX rotation types r/l; button still types a.
led-test.py: same knob test + ONE RGBW LED on MO at 8% brightness.
reasoning-knob.py: optional app shortcut example; does not drive the LED.

Changing code.py replaces the previous program. Copy your calibrated
REVERSE_ROTATION value into each new knob test. The reasoning example sends
Ctrl+Option+Command+Up/Down, but the app or OS must bind these shortcuts.
It does not read the app's reasoning level or create missing app commands.

The one-LED program uses the same MO/RGBW/8% LED configuration as our bench
program. A program running successfully is not proof of physical LED operation.
There is no automatic native Codex integration.

Follow https://codexmicro.diy/#wiring for wiring, checkpoints and the PDF.
Unplug USB before soldering or moving wires. Do not change the RAW bypass jumper.
The final 14-LED build requires a separate current-budget and power review.

Adafruit library licenses are in licenses; exact sources are in library-sources.json.

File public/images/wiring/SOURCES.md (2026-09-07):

# Wiring illustration references

Original supplier assets, displayed with SVG crops and wiring overlays in the guide. Copyright remains with the respective makers. These are reference images of individual components, not photographs of a tested assembled keyboard.

| Local file | Original asset | Product / reference |
| --- | --- | --- |
| kb2040.jpg | https://cdn-shop.adafruit.com/970x728/5302-18.jpg | https://learn.adafruit.com/adafruit-kb2040/pinouts |
| pixels.jpg | https://cdn-shop.adafruit.com/970x728/4776-01.jpg | https://www.adafruit.com/product/4776 |
| encoder.jpg | https://cdn-shop.adafruit.com/970x728/377-03.jpg | https://www.adafruit.com/product/377 |
| joystick-bottom.jpg | https://www.sparkfun.com/media/catalog/product/0/9/09426-03.jpg | https://www.sparkfun.com/thumb-slide-joystick.html |
| switch.webp | https://ueeshop.ly200-cdn.com/u_file/UPAW/UPAW819/2408/07/photo/Gateron-NewNorthPole20-Yellow-Switch-5pin-SMD9.webp | https://www.gateron.com/products/gateron-new-north-pole-yellow-20-switch-set |

The switch image is the manufacturer's component render. The controller, pixel, encoder and joystick images are product photos. DIP chip, passive components, white LEDs and encoder underside are explanatory vector drawings. Reference pinouts:

- TI SN74AHCT125N DIP-14 top view: https://www.ti.com/lit/ds/symlink/sn74ahct125.pdf (pages 3–4).
- PEC11 series terminal arrangement: https://cdn-shop.adafruit.com/datasheets/pec11.pdf (page 2).
- SparkFun joystick: underside contacts X / VCC / Y / GND, with GND nearest the pair of mounting tabs. The KB2040 build powers this passive joystick at **3.3V**, not the 5V in SparkFun's Arduino example.

The application uses the checked-in CircuitPython firmware's assignments. `scripts/check-wiring.mjs` checks the instructional map against that firmware. Hardware operation, physical fit, signal integrity and soldered connections require bench testing.

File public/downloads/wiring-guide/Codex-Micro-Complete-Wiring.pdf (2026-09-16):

# The entire keyboard, wire by wire

## KNOB / ENCODER

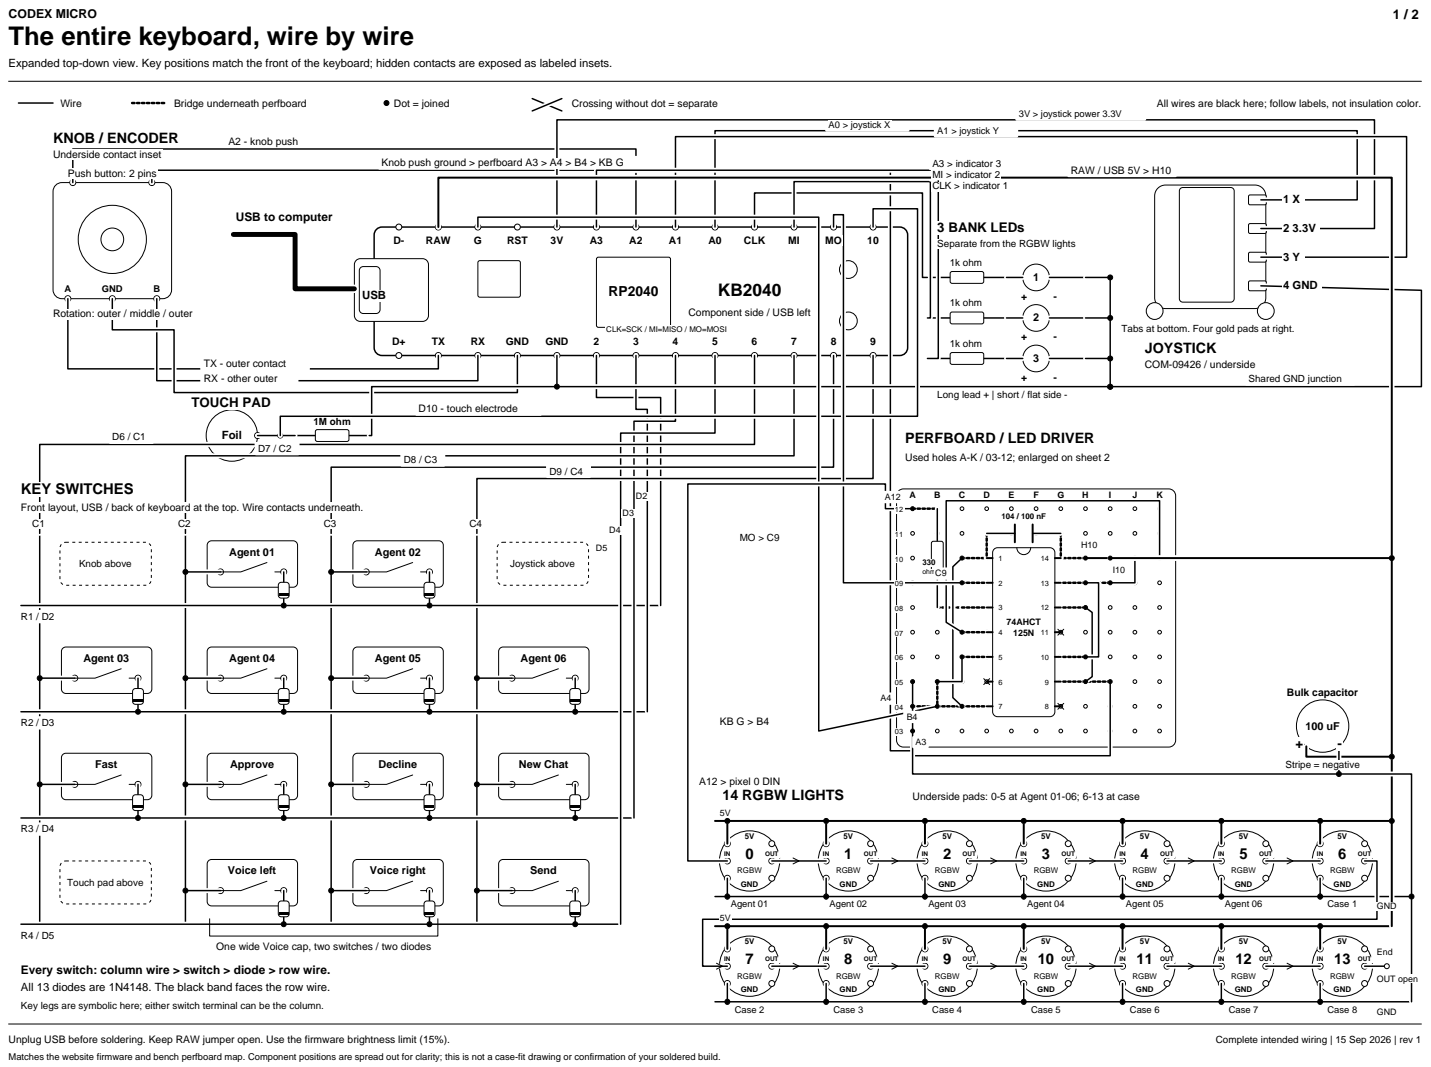
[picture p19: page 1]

Expanded top-down view. Key positions match the front of the keyboard; hidden contacts are exposed as labeled insets.

Knob push ground > perfboard A3 > A4 > B4 > KB G

3 BANK LEDs
Separate from the RGBW lights
1k ohm

Component side / USB left

Rotation: outer / middle / outer

CLK=SCK / MI=MISO / MO=MOSI

Tabs at bottom. Four gold pads at right.
JOYSTICK
COM-09426 / underside

TX - outer contact
RX - other outer
Long lead + | short / flat side - TOUCH PAD

PERFBOARD / LED DRIVER
Used holes A-K / 03-12; enlarged on sheet 2

KEY SWITCHES
Front layout, USB / back of keyboard at the top. Wire contacts underneath.

One wide Voice cap, two switches / two diodes

Every switch: column wire > switch > diode > row wire.
All 13 diodes are 1N4148. The black band faces the row wire.
Key legs are symbolic here; either switch terminal can be the column.

Matches the website firmware and bench perfboard map. Component positions are spread out for clarity; this is not a case-fit drawing or confirmation of your soldered build.

CODEX MICRO

# Inside the perfboard

Top/component side. Column A is at the left; row 01 is at the bottom. Dashed bridges are on the underside, seen through the board.

2 / 2

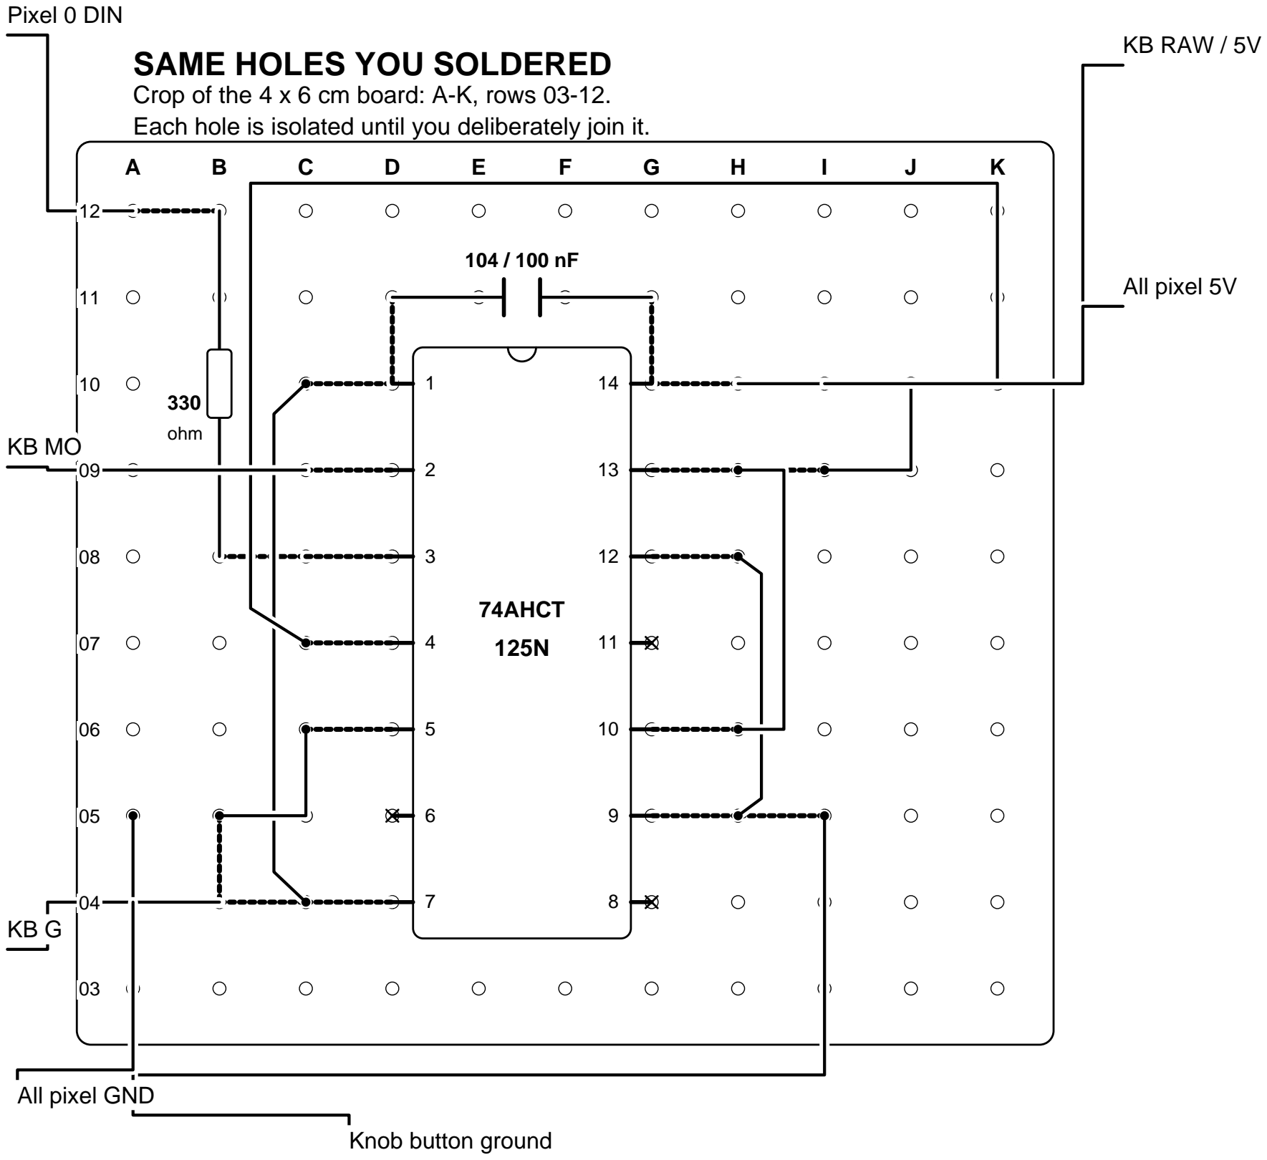
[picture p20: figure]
74AHCT 125N; ohm; SAME HOLES YOU SOLDERED; Pixel 0 DIN; Knob button ground; All pixel GND; KB RAW / 5V; All pixel 5V

Crop of the 4 x 6 cm board: A-K, rows 03-12. Each hole is isolated until you deliberately join it.

NOTCH points toward the column letters / higher row numbers. Looking underneath mirrors left and right. Locate the holes from above first.

Solid line = insulated wire on top. Short dashed line = bent lead + solder below. Small X = intentionally unused chip output; leave unconnected.

## WHAT EACH CHIP LEG DOES

SN74AHCT125N - the small chip translates only the LED data.

Pin | Hole | Function | Connect to
1 | D10 | /OE1 | GND - enables channel 1
2 | D9 | 1A input | KB2040 MO through C9
3 | D8 | 1Y output | 330 ohm resistor > A12 > pixel 0 DIN
4 | D7 | /OE2 | 5V - disables spare channel
5 | D6 | 2A input | GND
6 | D5 | 2Y output | Leave open
7 | D4 | GND | Common ground
8 | G4 | 3Y output | Leave open
9 | G5 | 3A input | GND
10 | G6 | /OE3 | 5V - disables spare channel
11 | G7 | 4Y output | Leave open
12 | G8 | 4A input | GND
13 | G9 | /OE4 | 5V - disables spare channel
14 | G10 | VCC | RAW / 5V through H10

### THE TWO COMPONENTS ALREADY ON THE BOARD

330 ohm resistor: B8 to B12. B8-C8-D8 and A12-B12 are bridges.
104 ceramic capacitor: D11 to G11. D11-D10 and G11-G10 are bridges. The capacitor crosses power and ground; it does not short them together.

### ADDITIONS FOR THE COMPLETE KEYBOARD

100 uF capacitor near the start of the light chain: + to 5V; stripe to GND.
More lights: each needs 5V + GND, plus data from the preceding DOUT. Joystick, touch and indicators share GND. Use a separate soldered junction from the spare GND hole; the illustration does not assign new perfboard holes.

## HOW TO READ THE REST OF THE KEYBOARD

Keys
A key closes a column-to-row path.
Diode black band faces its row.
Both Voice switches get a diode.

Knob + joystick
Knob center of 3 terminals = GND.
Other side: two pushbutton contacts. Joystick pads, from underside: X, 3V, Y, GND.

Lights
All 5V pads share power; all GND pads share ground. Only DATA chains: OUT of one > IN of the next. Pixel pads: underside, arrows left to right, 5V at top.

References checked against this project and manufacturer documentation:
KB2040: learn.adafruit.com/adafruit-kb2040/pinouts | Level shifter: ti.com/lit/ds/symlink/sn74ahct125.pdf
NeoPixels: adafruit.com/product/4776 | Encoder: adafruit.com/product/377 | Joystick: sparkfun.com/thumb-slide-joystick.html
Project source: data/wiring.json + wiring-guide/connections.json + downloads/firmware/code.py on codexmicro.diy.
A3 / A4 here are PERFBOARD coordinates, not the analog pins on the KB2040. | Complete intended wiring | 15 Sep 2026 | rev 1
Matches the website firmware and bench perfboard map. Component positions are spread out for clarity; this is not a case-fit drawing or confirmation of your soldered build.

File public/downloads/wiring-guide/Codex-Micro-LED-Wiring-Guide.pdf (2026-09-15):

CODEX MICRO / YOUR LED CIRCUIT

# What we just built

A small circuit that lets your KB2040 control one colored LED.

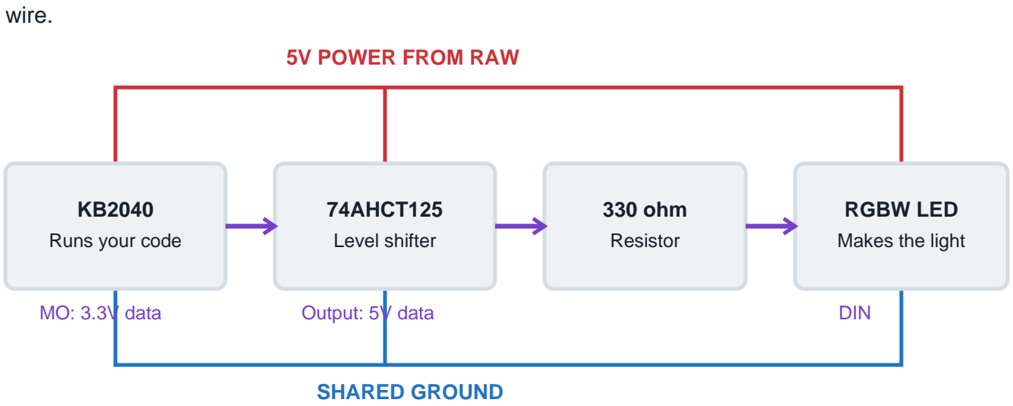
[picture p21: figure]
wire.; 5V POWER FROM RAW; SHARED GROUND; KB2040 Runs your code; 74AHCT125 Level shifter; 330 ohm Resistor; RGBW LED Makes the light; MO: 3.3V data; Output: 5V data; DIN

Wiring reference - September 15, 2026 | 1 / 6

Think of the KB2040 as the person speaking, and the level shifter as a speaker that repeats the message louder. The message is a color instruction. Power reaches the LED on a separate

### Power

RAW powers the chip and LED. The LED does not get its power through the resistor.

### Ground

The chip, LED and knob share a path back to KB2040 G. Think of the perfboard as a shared junction.

### Color instructions

MO sends data to the chip. The chip passes it through the resistor to the LED's DIN pad.

The other parts: the little 104 capacitor smooths brief power disturbances. The remaining jumper wires keep the chip's three spare channels steady and switched off.

The perfboard is a holder with separate metal pads. Adjacent holes are not connected until you join them. Knob rotation and button signal wires are outside this LED diagram.

Reading the guide
2: full layout 3: data 4: power 5: ground 6: connection reference

Based on connections you reported; not a photo or electrical verification.

KB2040 pinout (https://learn.adafruit.com/adafruit-kb2040/pinouts) | Chip datasheet (https://www.ti.com/lit/ds/symlink/sn74ahct125.pdf) | RGBW LED (https://www.adafruit.com/product/4776)

# Your complete perfboard layout

Top view: letters across the top, chip notch facing up.

Solid lines: insulated wires on top. Dashed lines: bare solder links underneath.

Colors show function, not your wire insulation. Crossings alone do not connect.

# Follow the color instructions

Purple is the data path. Other connections are faded.

KB MO > C9-D9 > chip pin 2 > chip pin 3 at D8 > B8 > resistor > B12-A12 > DIN.

The resistor carries the signal; it is not the LED power supply.

# Follow the power

Red is the RAW power network. Other connections are faded.

RAW > H10-G10 powers the chip; H10-I10 powers the LED.

The red jumpers to pins 4, 10 and 13 switch the three unused channels OFF.

# Follow the shared ground

Blue connects the chip, LED and moved knob ground wire.

Knob > A3-A4 > B4 > KB G. LED GND also joins A4.

Grounding pin 1 turns our active channel ON; pins 5, 9 and 12 are unused inputs.

# Hole-by-hole reference

Perfboard coordinates are always read from the TOP, even for underside joints.

Connection | Top-side endpoints | Join underneath
Active enable | C10 to C4 | C10-D10; C4-D4
KB ground | B4 to KB G | B4-C4
KB power | H10 to KB RAW | H10-G10
Data input | C9 to KB MO | C9-D9
LED data | A12 to LED DIN | A12-B12
LED ground | A4 to LED GND | A4-B4
LED power | I10 to LED 5V | I10-H10
Spare input 1 | C6 to B5 | C6-D6; B5-B4
Spare inputs 2 + 3 | H5 to H8 | H5-G5; H8-G8
Ground that pair | I5 to A5 | I5-H5; A5-A4
Disable pair | H6 to H9 | H6-G6; H9-G9
Power that pair | I9 to J10 | I9-H9; J10-I10
Last disable | C7 to K10 | C7-D7; K10-J10
Moved knob ground | A3 to knob ground | A3-A4
104 capacitor | D11 to G11 | D11-D10; G11-G10
330 ohm resistor | B8 to B12 | B8-C8-D8; B12-A12

Leave these chip outputs unconnected: pin 6 at D5, pin 8 at G4, and pin 11 at G7.

Read a row like this: "C6 to B5" is one insulated wire across the top. Underneath, one bare end joins C6 to D6; the other joins B5 to B4.

Unplug USB before moving or soldering wires. An unlit LED alone does not identify a wiring fault.

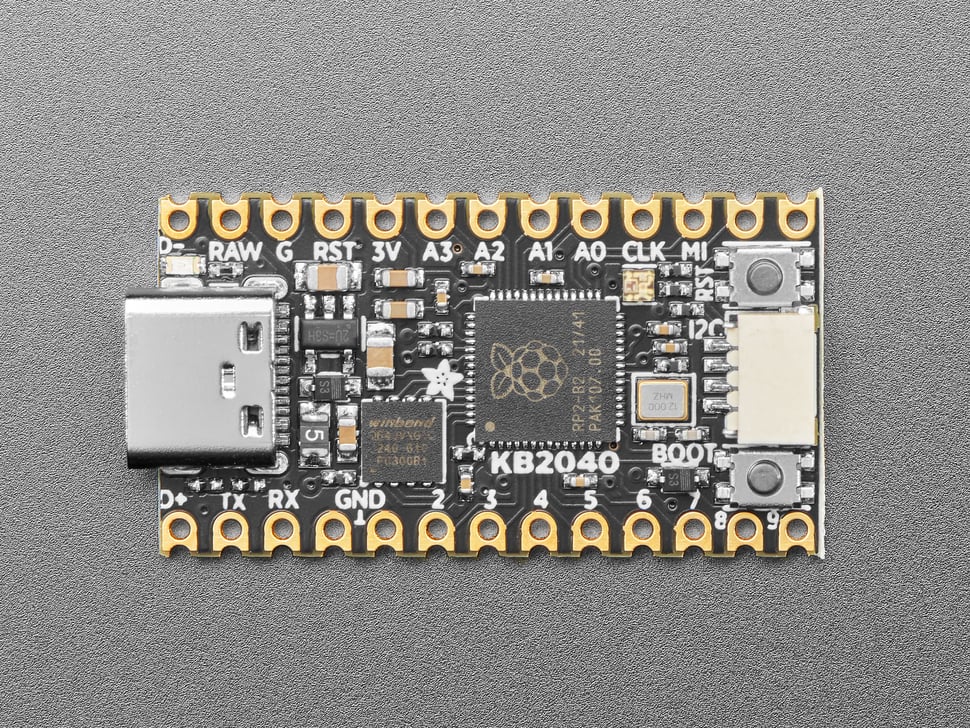
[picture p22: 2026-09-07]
public/images/wiring/kb2040.jpg

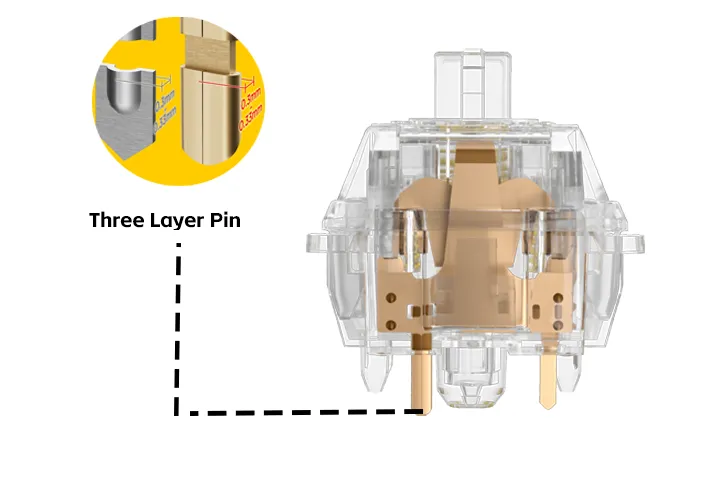
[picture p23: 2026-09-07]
public/images/wiring/switch.webp

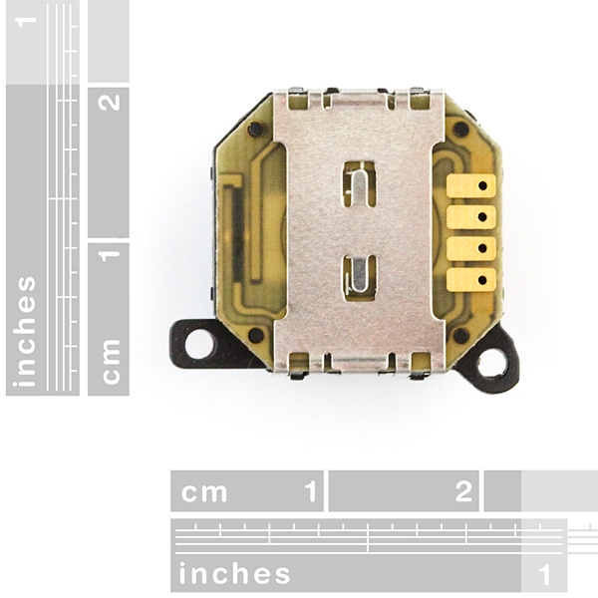
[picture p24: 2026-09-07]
public/images/wiring/joystick-bottom.jpg

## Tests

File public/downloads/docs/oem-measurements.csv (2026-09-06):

measurement | unit | value | how_to_measure
PCB width | mm |  | Calipers across bare PCB
PCB depth | mm |  | Calipers across bare PCB
PCB thickness | mm |  | Calipers at clear board edge
Hole 1 X from PCB center | mm |  | Top view right is positive
Hole 1 Y from PCB center | mm |  | Top view rear is positive
Hole 2 X from PCB center | mm |  | Top view right is positive
Hole 2 Y from PCB center | mm |  | Top view rear is positive
Hole 3 X from PCB center | mm |  | Top view right is positive
Hole 3 Y from PCB center | mm |  | Top view rear is positive
Hole 4 X from PCB center | mm |  | Top view right is positive
Hole 4 Y from PCB center | mm |  | Top view rear is positive
Mount hole diameter | mm |  | Pin gauge or calipers
Tallest underside component | mm |  | Include connectors and cable bends
USB port center X from PCB center | mm |  | At port opening
USB port height above PCB | mm |  | At port center
Rear button location | mm |  | X/Y/Z of center
Battery envelope | mm |  | Length width thickness; do not compress cell
Antenna location and keepout | mm |  | Photo with ruler plus board markings
Touch electrode location | mm |  | X/Y and gap to exterior surface
Perimeter LED locations | mm |  | Top and underside photos with ruler
Optical diffuser/lightpipe envelope | mm |  | Reuse the original if possible
Original switch plate seat height | mm |  | From PCB top surface
Case outer width and depth | mm |  | Reference for exterior reconstruction
Original keycap stem locations | mm |  | Confirm the two sockets under wide key

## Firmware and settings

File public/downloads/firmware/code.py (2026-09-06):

"""DIY Micro Rev A / KB2040 / CircuitPython. Hardware prototype, not OEM firmware.
Default keys are F13..F24; joystick sends arrows; dial scrolls.
Install lib/adafruit_hid, neopixel.mpy and adafruit_pixelbuf.mpy.
The USB data port accepts a newline-delimited JSON color command:
  {"led":0,"rgb":[0,120,255]}
It does NOT read Codex task state automatically.
"""
import time, json
import board, keypad, digitalio, analogio, rotaryio, touchio
import usb_hid, usb_cdc, neopixel
from adafruit_hid.keyboard import Keyboard
from adafruit_hid.keycode import Keycode
from adafruit_hid.mouse import Mouse
from logic import KeyState, direction, rgbw

matrix=keypad.KeyMatrix(row_pins=(board.D2,board.D3,board.D4,board.D5),
    column_pins=(board.D6,board.D7,board.D8,board.D9),
    columns_to_anodes=True,interval=.005,debounce_threshold=3)
encoder=rotaryio.IncrementalEncoder(board.TX,board.RX)
encoder_button=keypad.Keys((board.A2,),value_when_pressed=False,pull=True,
    interval=.005,debounce_threshold=3)
joy_x=analogio.AnalogIn(board.A0); joy_y=analogio.AnalogIn(board.A1)
touch=touchio.TouchIn(board.D10)  # 1 MOhm external pulldown REQUIRED
pixels=neopixel.NeoPixel(board.MOSI,14,brightness=.15,auto_write=False,
    pixel_order=neopixel.GRBW)
indicators=[]
for pin in (board.SCK,board.MISO,board.A3):
    d=digitalio.DigitalInOut(pin);d.switch_to_output(value=False);indicators.append(d)
kbd=Keyboard(usb_hid.devices);mouse=Mouse(usb_hid.devices)
keys=KeyState()
# Three banks retain identical F13-F24 usages but add modifiers to banks 2/3.
# Configure them in your OS shortcut app, or edit these mappings.
FUNCTION_KEYS=[getattr(Keycode,'F'+str(i)) for i in range(13,25)]
MODIFIERS=[(),(Keycode.LEFT_SHIFT,),(Keycode.LEFT_CONTROL,)]
ARROWS={'left':Keycode.LEFT_ARROW,'right':Keycode.RIGHT_ARROW,
        'up':Keycode.UP_ARROW,'down':Keycode.DOWN_ARROW}
active_chords={};held_usages=set();layer=0
# Sample at rest. Do not touch the stick while connecting USB.
sx=sy=0
for _ in range(32):
    sx+=joy_x.value;sy+=joy_y.value;time.sleep(.005)
center=(sx//32,sy//32)
last_direction=None;last_touch=False;touch_time=0;last_position=encoder.position
serial=usb_cdc.data;buffer=bytearray()

def sync_keyboard():
    desired=set()
    for chord in active_chords.values():desired.update(chord)
    for key in held_usages-desired:kbd.release(key)
    for key in desired-held_usages:kbd.press(key)
    held_usages.clear();held_usages.update(desired)

def set_layer(value):
    global layer
    layer=value%3
    for i,led in enumerate(indicators):led.value=(i==layer)
    # This is bank feedback; these colors do not represent agent status.
    colors=((0,30,55,0),(35,0,40,0),(30,25,0,0))
    pixels.fill(colors[layer]);pixels.show()

def serial_command(line):
    try:
        data=json.loads(line)
        index=data['led']
        if not isinstance(index,int) or not 0<=index<14:raise ValueError('LED index 0..13')
        pixels[index]=rgbw(data['rgb']);pixels.show()
    except (ValueError,KeyError,TypeError) as exc:
        print('Color command ignored:',exc)

set_layer(0)
try:
    while True:
        changed=False
        event=matrix.events.get()
        while event:
            transition=keys.update(event.key_number,event.pressed)
            if transition:
                logical,down=transition
                if down:active_chords[logical]=MODIFIERS[layer]+(FUNCTION_KEYS[logical],)
                else:active_chords.pop(logical,None)
                changed=True
            event=matrix.events.get()
        if matrix.events.overflowed:
            keys=KeyState();active_chords.clear();matrix.events.clear();matrix.reset();changed=True
        event=encoder_button.events.get()
        while event:
            if event.pressed:active_chords['dial']=(Keycode.ENTER,)
            else:active_chords.pop('dial',None)
            changed=True;event=encoder_button.events.get()
        position=encoder.position;delta=position-last_position
        if delta:mouse.move(wheel=max(-10,min(10,delta)));last_position=position
        # First prototype defaults to normal arrow keys. Reverse Y here if required.
        new_direction=direction(joy_x.value,joy_y.value,center,last_direction)
        if new_direction!=last_direction:
            if new_direction:active_chords['joy']=(ARROWS[new_direction],)
            else:active_chords.pop('joy',None)
            changed=True;last_direction=new_direction
        touched=touch.value;now=time.monotonic()
        if touched and not last_touch and now-touch_time>.4:
            set_layer(layer+1);touch_time=now
        last_touch=touched
        if changed:sync_keyboard()
        if serial and serial.connected and serial.in_waiting:
            chunk=serial.read(min(serial.in_waiting,128))
            if chunk:buffer.extend(chunk)
            while b'\n' in buffer:
                line,_,rest=buffer.partition(b'\n');buffer=bytearray(rest)
                serial_command(line)
            if len(buffer)>512:buffer.clear()
        time.sleep(.002)
finally:
    kbd.release_all();pixels.fill((0,0,0,0));pixels.show()

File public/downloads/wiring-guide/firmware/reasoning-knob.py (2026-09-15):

"""Codex Micro staged bench test - CircuitPython on Adafruit KB2040.
Install lib/adafruit_hid. Back up your current code.py before replacing it.
Unplug USB before changing wiring. No matrix or joystick needed for this test.
"""
import time
import board
import keypad
import usb_hid
from adafruit_hid.keyboard import Keyboard
from adafruit_hid.keycode import Keycode

import rotaryio

# If right types l (or decreases reasoning), toggle this and save.
# Keep the value calibrated for YOUR TX/RX wiring when changing tests.
REVERSE_ROTATION = True
encoder = rotaryio.IncrementalEncoder(board.TX, board.RX, divisor=4)
keyboard = Keyboard(usb_hid.devices, timeout=10)
button = keypad.Keys((board.A2,), value_when_pressed=False, pull=True,
                     interval=0.01, debounce_threshold=3)
time.sleep(0.2)
held = False
event = button.events.get()
while event is not None:
    held = event.pressed
    event = button.events.get()
last_position = encoder.position
print("KNOB READY: button types a")
try:
    while True:
        event = button.events.get()
        while event is not None:
            if event.pressed and not held:
                keyboard.send(Keycode.A)
                print("PRESS: a")
            held = event.pressed
            event = button.events.get()
        position = encoder.position
        delta = position - last_position
        last_position = position
        if REVERSE_ROTATION:
            delta = -delta
        if delta:
            # The target app/OS must bind these shortcuts to real commands.
            # This firmware cannot read or create a reasoning-level command.
            key = Keycode.UP_ARROW if delta > 0 else Keycode.DOWN_ARROW
            for _ in range(min(abs(delta), 10)):
                keyboard.send(Keycode.CONTROL, Keycode.ALT, Keycode.GUI, key)
                time.sleep(0.08)
            print("TURN:", delta)
        time.sleep(0.005)
finally:
    keyboard.release_all()
    button.deinit()
    encoder.deinit()

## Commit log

2026-09-06 Build interactive Codex Micro DIY guide
    [01_case.step, 01_case.stl, 02_switch_plate.step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]
2026-09-06 Set the Vercel framework to Next.js
2026-09-06 Add labeled keypad overview and separate print and buy checklists
2026-09-06 Add interactive assembly lessons with focused visuals and explanations
2026-09-07 Add photo-based interactive wiring guide
2026-09-13 Flatten printable keycaps and bevel their rims
    [08_keycap_1u.step, 08_keycap_1u.stl, 09_keycap_2u_dual_stem.step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]
2026-09-14 Publish joystick fit-test CAD kit and mounting hardware
    [04_joystick_fit_holder_v1.step, 04_joystick_fit_holder_v1.stl, 04_shim_A_05_v1.step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]
2026-09-14 Integrate joystick mount into plate and add print-first corner test
    [02_integrated_top_plate_v2_WAIT.step, 02_integrated_top_plate_v2_WAIT.stl, 04_joystick_corner_v2_PRINT_FIRST.step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]
2026-09-15 Simplify joystick mount to flat plate with exposed nuts
    [02_flat_top_plate_v3_WAIT.step, 02_flat_top_plate_v3_WAIT.stl, 04_flat_joystick_corner_v3_PRINT_FIRST.step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]
2026-09-15 Add removable snap-baffle fit sample and candidate plate
    [02_flat_joystick_snap_baffle_plate_WAIT.step, 02_flat_joystick_snap_baffle_plate_WAIT.stl, 07_baffle_clip_test_plate_v1.step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]
2026-09-15 Recess LED seat and verify insulation clearance from switch pins
    [02_flat_joystick_snap_baffle_plate_WAIT.step, 07_baffle_clip_test_plate_v1.step, 07_snap_baffle_v1.step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]
2026-09-15 Design removable two-layer baffle tray with exposed screw fasteners
    [02_two_layer_top_plate_WAIT.step, 02_two_layer_top_plate_WAIT.stl, 07_six_light_tray_WAIT.step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]
2026-09-15 Reuse existing M3 screws and heat-set inserts for baffle tray
    [07_heatset_baffle_sample_v3.step, 07_heatset_baffle_sample_v3.stl, 07_heatset_six_light_tray_v3_WAIT.step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]
2026-09-15 Replace wiring section with staged knob and perfboard lessons
    [build-wiring-downloads.py, build-wiring-lessons.py, button-test.py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]
2026-09-15 Publish current STEP set for flat joystick and heat-set tray
    [02_two_layer_top_plate_WAIT.step, 07_two_layer_top_sample.step]
2026-09-15 Add assembled LED driver PCB manufacturing package
    [bom-jlcpcb.csv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]
2026-09-15 Fix JLCPCB placement coordinate direction
    [codex-micro-led-driver-B_Cu.gbl, codex-micro-led-driver-B_Mask.gbs, codex-micro-led-driver-B_Silkscreen.gbo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]
2026-09-15 Align JLCPCB component rotations
    [codex-micro-led-driver-B_Cu.gbl, codex-micro-led-driver-B_Mask.gbs, codex-micro-led-driver-B_Silkscreen.gbo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]
2026-09-15 Enlarge tray LED openings to original 10 by 4 mm size
    [02_two_layer_top_plate_WAIT.step, 07_heatset_baffle_sample_v4.step, 07_heatset_baffle_sample_v4.stl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]
2026-09-15 Add exact LED mounting tape to shopping checklist
    [bom.csv]
2026-09-16 Design hidden tray fasteners and removable joystick adapter v5
    [02_top_plate_v5_WAIT.step, 02_top_plate_v5_WAIT.stl, 04_joystick_adapter_v5.step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]
2026-09-16 Point archived joystick guides to current mounting design
2026-09-16 Synchronize current CAD download archives
2026-09-16 Add complete monochrome keyboard wiring diagram and printable PDF
